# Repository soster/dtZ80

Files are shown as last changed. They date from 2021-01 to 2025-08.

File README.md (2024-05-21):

# dtZ80 - A simple 8 Bit Computer based on the Z80 CPU

This started as a project during the second Corona lockdown, where I had to much free time.
I wanted to design my own 8 Bit computer and decided to use the Z80 CPU.
The first idea was to use a MOS 6502 because a variant of that powers the C64, a computer I used much in my childhood.
The Z80 is easier to source where I live so I used that instead.

I started on breadboards but quickly discovered the limits of that so I soldered some prototypes and finally designed some PCBs with kicad.

The bus is compatible to the Bus of the [RC2014 Z80 computer](https://rc2014.co.uk/), so I can exchange expansion cards.

This documentation now covers the new "Black Edition" of the dtZ80 (Rev 1), a larger board without the need to use extension cards. Previous prototypes had a common bus board and extension cards for the CPU, RAM etc. All software for the previous prototypes can be found at `asm/prototype` for historical reasons.

The dtZ80 uses a Z80 CPU with clocked with 7.3728 Mhz (which doubles as a clock for serial communication), a Z80 SIO for serial communication, a CTC counter timer, 32kb of RAM and 32kb of ROM and a AY-3-8910A sound chip. It uses a single seven segment display for debugging purposes and a 4 line, 20 characters per line LCD for text output.

## Tools

* [rasm](https://github.com/mkoloberdin/rasm) is used as the assembler.
* [Visual Studio Code](https://code.visualstudio.com/) is used as an editor and enviroment for assembler
* [Minipro](https://gitlab.com/DavidGriffith/minipro/) is used to flash the EEPROMs, the hardware is a TL866 II PLUS
* [ticks](https://github.com/z88dk/z88dk) from the z88dk project is used as an emulator / simulator
* A usb to ttl converter for serial communication (can be switched to 5V levels, only needs TX and RX)

## Images

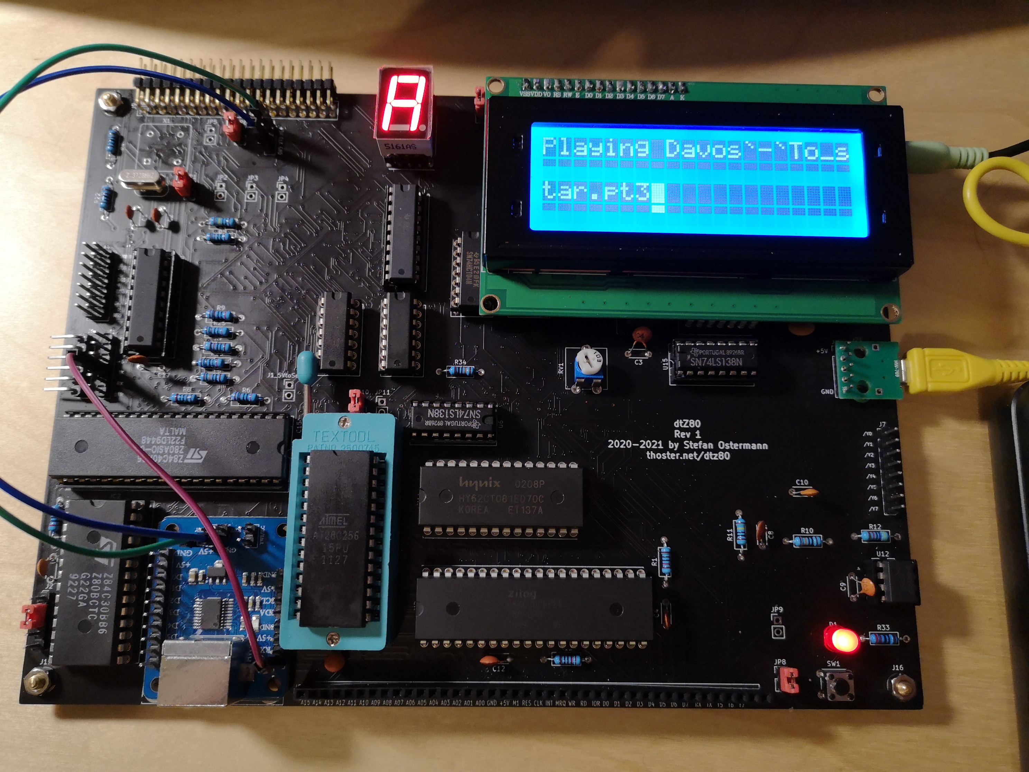
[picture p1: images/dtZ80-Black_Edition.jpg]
dtZ80 Black Edition


### Address Space

Address lines are assigned by a 74LS138 IC (U6) which activates
or deactivates the correct ICs.

    $00: I/O port 7 segment (A0-A7=0)
    $04: LCD command I/O port (A5=1)
    $05: LCD data I/O port (A5=1,A0=1)
    $40: SIO Data Channel A
    $42: SIO Control Channel A
    $60: CTC Channel 0
    $61: CTC Channel 1
    $62: CTC Channel 2
    $63: CTC Channel 3
    $80: Sound Register
    $81: Sound Data

#### LCD

The black edition uses a 4 line, 20 column LCD Display (2004A V1.1) probably based on the HD44780 Chip [(Datasheet)](https://www.sparkfun.com/datasheets/LCD/HD44780.pdf).
It behaves strangely if we send character by character to it, it uses line 3 after line 1 and the lines 2 and 4 are not usable. We have to manually set the DDRAM address holding the character position according to the current line:

    Line 1: $00 - $13
    Line 2: $40 - $53
    Line 3: $14 - $27
    Line 4: $54 - $67

I assume this is due to backwarts compatibility to 2 line displays.

#### Parallel Interface

The 8 Bit parallel Interface is used to connect a lcd screen mainly. Due to an error while designing the pcb, it has the following pins (GND=Pin 1):

Parallel Port

#### Serial Interface

The serial interface is provided by the Z80 SIO chip (SI0/0). It has two channels, A (J1) and B (J6). The clock is provided by the CTC chip for channel A. If you want to use channel B, you have to connect the clock from the pin CTS from J1 to CTS on J6. Please note that RX and TX are labeled from the point of view of the external device, RX is connected to TX on the SIO and vice versa (this maybe was a stupid decistion).

If you are working with linux and you have a usb to serial converter connected to /dev/ttyUSB0 you can use `screen` to enter serial terminal mode:

    screen /dev/ttyUSB0 19200

To enter serial mode of the dtZ80 simply press enter now.

Screen commands consist of "C-a" or ctrl+a (holding down the control key, and then pressing the 'a' key, then releasing both), to enter the command input mode, then commands may be entered with another key stroke.
To disconnect from the session: Ctrl+a, Ctrl+d, you can then use this to reattach to the session:

    screen -r

To quit screen and close connection: ctrl+a, k.

### CTC Clock Timer Chip

TODO

### PS/2 Keyboard module

For ps/2 keyboard to serial conversion I use a "PS2 Keyboard Driver Serial Port Transmission Module".
 
1. connect TX from the module to TX from J1. The module communicates via serial in 19.200 Baud, 1 Stop bit, no parity.

### Sound

TODO

### Simulator / Emulator

The simulator `ticks` from [https://github.com/z88dk/z88dk](https://github.com/z88dk/z88dk) can be used as a simulator. It provides character output for debugging purposes. Use it like this on assembled binary files:

```
z88dk.z88dk-ticks -iochar 5 bios.bin
```
`-iochar 5` puts out characters just like for the LCD of the dtz80.

## Next steps / TODOs

* Further develop the bios
* Tiny Basic example code: http://cpuville.com/Code/tinybasic2dms_asm.txt
* Document all features

### Graphics

Graphics is not finished yet. These are some ideas:
Based on: TMS9918A
Problem: Works only with DRAM for SRAM
Looks like you will need to latch the address bits 8-15 when RAS goes low
Connect (/CAS0 AND /CAS1) to /OE on the SRAM and use one of them for A16 also
Important: Clock 10.738635 Mhz, Type ‎MP107-E‎ for video timing
Use schematics from: https://github.com/jblang/TMS9918A

## Links
* [Bread 80](https://bread80.com/) A Z80 on breadboards
* [RC2014](https://rc2014.co.uk/) Another Z80 project
* [LM80C Color Computer](https://hackaday.io/project/165246-lm80c-color-computer) Another Z80 Computer, interesting because of graphics output
* [Z80 Assembler for dummies](https://www.msx.org/wiki/Z80_Assembler_for_Dummies) Z80 Assembler Guide

## More images
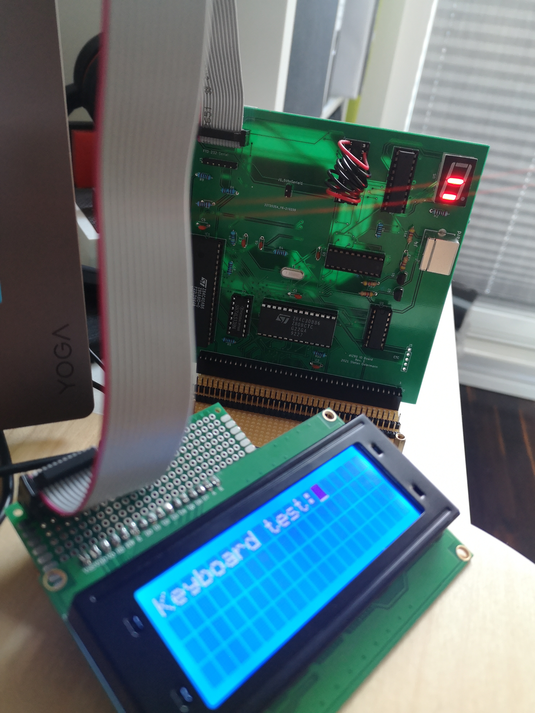
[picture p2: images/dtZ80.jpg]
dtZ80

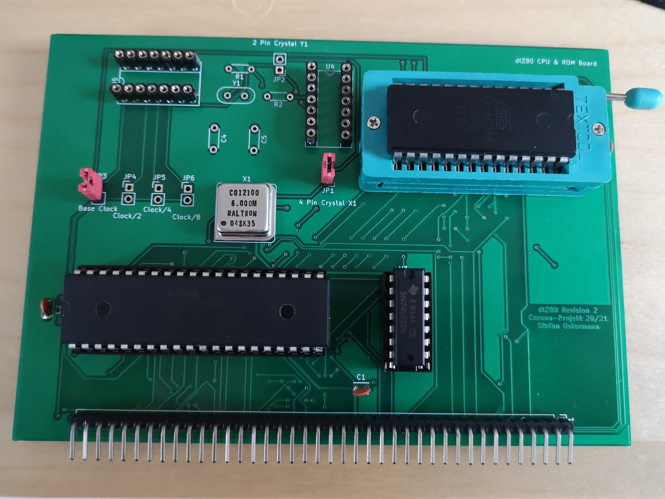
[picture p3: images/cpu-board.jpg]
CPU Card


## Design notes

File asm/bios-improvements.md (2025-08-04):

# dtZ80 BIOS Improvement Recommendations

## Critical Fixes Required

### 1. Fix Syntax Error
**File:** `asm/dtz80-lib.inc`
**Issue:** Standalone 'd' character in STARTUP_SOUND routine
**Fix:** Remove the erroneous 'd' character

### 2. Fix Memory Map
**Current Issue:** RAM starts at $8000 but ROM should end at $7FFF
**Recommended Memory Map:**
```
$0000-$7FFF: ROM (32KB)
$8000-$FFFF: RAM (32KB)
$8000-$8FFF: System variables and buffers
$9000-$EFFF: User RAM
$F000-$FFEF: Stack space
$FFF0-$FFFF: Reserved for I/O
```

### 3. Proper Interrupt Vector Setup
```assembly
; Set interrupt vector base
ld a, $00
ld i, a
im 2

; Calculate proper interrupt vectors
; SIO Channel A RX: Vector base + $0C
; SIO Special RX:   Vector base + $0E
```

## Major Improvements

### 4. Enhanced LCD Library
Replace fixed delays with busy flag checking:
```assembly
LCD_WAIT_BUSY:
    push af
    in a, (LCD_COMMAND)    ; Read busy flag
    bit 7, a               ; Check busy bit
    jr nz, LCD_WAIT_BUSY   ; Wait if busy
    pop af
    ret
```

### 5. Robust Error Handling
```assembly
SPEC_RX_CONDITON:
    push af
    push hl
    
    ; Check error type
    ld a, 1
    out (SIO_CA), a        ; Select RR1
    in a, (SIO_CA)         ; Read error status
    
    bit 6, a               ; Overrun error?
    jr nz, HANDLE_OVERRUN
    bit 5, a               ; Framing error?
    jr nz, HANDLE_FRAMING
    bit 4, a               ; Parity error?
    jr nz, HANDLE_PARITY
    
    ; Clear error and continue
    call RX_EMP
    pop hl
    pop af
    ei
    reti

HANDLE_OVERRUN:
    ; Log error and reset
    call RX_EMP
    ; Could increment error counter here
    jr ERROR_EXIT
```

### 6. Improved Constants Definition
```assembly
; Memory Map Constants
ROM_START       equ $0000
ROM_END         equ $7FFF
RAM_START       equ $8000
RAM_END         equ $FFFF
STACK_TOP       equ $FFEF

; I/O Port Constants  
LCD_BASE        equ $04
SEVENSEG_BASE   equ $00
SIO_BASE        equ $40
CTC_BASE        equ $60
SOUND_BASE      equ $80

; System Constants
BAUD_RATE       equ 19200
CPU_FREQ        equ 7372800
```

### 7. Enhanced Startup Sequence
```assembly
MAIN:
    di                      ; Disable interrupts during init
    ld sp, STACK_TOP        ; Set stack pointer
    
    ; Hardware initialization
    call INIT_MEMORY        ; Clear and test RAM
    call INIT_CTC           ; Setup CTC
    call INIT_SIO           ; Setup SIO
    call INIT_SOUND         ; Setup AY-3-8910A
    call INIT_LCD           ; Setup LCD
    
    ; System initialization
    call INIT_VARIABLES     ; Initialize system variables
    call INIT_INTERRUPTS    ; Setup interrupt vectors
    
    ; Display startup message
    call DISPLAY_BANNER
    call POST_TEST          ; Power-on self test
    
    ei                      ; Enable interrupts
    jp MAIN_LOOP
```

### 8. Better Command Processing
```assembly
; Command table structure
CMD_TABLE:
    dw CMD_CLEAR, OC_CLEAR
    dw CMD_VERSION, OC_VERSION  
    dw CMD_RESET, OC_RESET
    dw CMD_PLAY, OC_PLAY
    dw 0                    ; End marker

CHECK_OPCODE:
    ld hl, CMD_TABLE
CHECK_LOOP:
    ld e, (hl)              ; Get command handler address
    inc hl
    ld d, (hl)
    inc hl
    ld a, d
    or e                    ; Check for end marker
    ret z                   ; No more commands
    
    push de                 ; Save handler address
    ld e, (hl)              ; Get command string address
    inc hl
    ld d, (hl)
    inc hl
    
    push hl                 ; Save table position
    ld hl, LAST_OPCODE
    ld bc, OPCODE_LENGTH
    call STRCMP
    pop hl                  ; Restore table position
    pop de                  ; Restore handler address
    
    jr z, EXECUTE_COMMAND   ; Found match
    jr CHECK_LOOP           ; Try next command

EXECUTE_COMMAND:
    ex de, hl               ; Handler address to HL
    jp (hl)                 ; Execute command
```

## Minor Improvements

### 9. Code Organization
- Separate hardware-specific code into modules
- Create proper header files with constants
- Add comprehensive comments
- Use consistent naming conventions

### 10. Additional Features to Consider
- Watchdog timer support
- Better debugging facilities
- Configuration storage in EEPROM
- More robust PS/2 keyboard handling
- Sound effects library
- Simple file system for storing programs

### 11. Testing Improvements
- Add comprehensive POST tests
- Memory test routines
- I/O port test routines
- Interrupt test routines

## Implementation Priority

1. **High Priority:** Fix syntax error and memory map
2. **High Priority:** Implement proper interrupt handling
3. **Medium Priority:** Improve LCD library with busy flag checking
4. **Medium Priority:** Enhanced error handling
5. **Low Priority:** Code organization and additional features

These improvements will make your dtZ80 BIOS more robust, maintainable, and feature-rich while maintaining compatibility with the RC2014 bus standard.

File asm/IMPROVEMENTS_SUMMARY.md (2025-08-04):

# dtZ80 BIOS Improvements Implementation Summary

## Completed Fixes and Improvements

### 1. ✅ **CRITICAL: Fixed Syntax Error**
- **File:** `asm/dtz80-lib.inc`
- **Issue:** Removed erroneous standalone 'd' character in STARTUP_SOUND routine
- **Status:** FIXED - This was preventing assembly

### 2. ✅ **HIGH PRIORITY: Fixed Memory Map**
- **Files:** `asm/dtz80-lib.inc`, `asm/bios.asm`, `asm/debug-bios.inc`
- **Changes:**
  - Added proper memory map constants (ROM_START, ROM_END, RAM_START, RAM_END)
  - Set STACK_TOP to $FFEF (leaving space for I/O at top of memory)
  - Updated STACKPOINTER to use STACK_TOP
  - Fixed all references to use STACKPOINTER consistently
- **Status:** IMPLEMENTED

### 3. ✅ **HIGH PRIORITY: Improved Interrupt Handling**
- **File:** `asm/bios.asm`
- **Changes:**
  - Enhanced interrupt vector setup with better documentation
  - Improved interrupt mode 2 initialization
  - Added proper comments explaining vector calculation
- **Status:** IMPLEMENTED

### 4. ✅ **MEDIUM PRIORITY: Enhanced Error Handling**
- **File:** `asm/bios.asm`
- **Changes:**
  - Completely rewrote SPEC_RX_CONDITON handler
  - Added proper SIO error type detection (overrun, framing, parity)
  - Implemented specific error handling for each error type
  - Added proper register preservation and error cleanup
  - Added error reset command to clear SIO error flags
- **Status:** IMPLEMENTED

### 5. ✅ **MEDIUM PRIORITY: Improved LCD Library with Busy Flag Checking**
- **File:** `asm/lcd-lib.inc`
- **Changes:**
  - Replaced fixed delays with busy flag checking in LCD_WAIT
  - Added timeout protection to prevent infinite loops
  - Implemented fallback delay mechanism if busy flag fails
  - More reliable LCD communication
- **Status:** IMPLEMENTED

### 6. ✅ **Additional Improvements**
- **File:** `asm/dtz80-lib.inc`
- **Changes:**
  - Added system constants (BAUD_RATE, CPU_FREQ)
  - Better organization of constants
- **Status:** IMPLEMENTED

## Testing Instructions

### Prerequisites
Install rasm assembler:
```bash
# Download and install rasm from: https://github.com/mkoloberdin/rasm
```

### Assembly Test
```bash
cd asm
rasm bios.asm bios
```

### Simulation Test (if z88dk is available)
```bash
# Test with simulator
z88dk-ticks -iochar 5 bios.bin

# Test with symbols for debugging
rasm -s -sa bios.asm bios
z88dk-ticks -x bios.sym -pc 0 -d -iochar 5 bios.bin
```

## Key Benefits of These Improvements

### Reliability
- **Busy flag checking** makes LCD operations more reliable across different LCD modules
- **Enhanced error handling** prevents system crashes from serial communication errors
- **Proper memory map** prevents conflicts between ROM and RAM

### Maintainability
- **Better constants organization** makes code easier to understand and modify
- **Improved documentation** explains complex interrupt handling
- **Consistent naming** throughout the codebase

### Robustness
- **Timeout protection** prevents infinite loops in LCD operations
- **Proper error recovery** handles serial communication problems gracefully
- **Stack placement** leaves room for future I/O expansion

## Remaining Recommendations (Future Work)

### Low Priority Improvements
1. **Command Table System** - Implement table-driven command processing for easier expansion
2. **Memory Test Routines** - Add comprehensive POST tests
3. **Configuration Storage** - Add EEPROM support for storing settings
4. **Enhanced Sound Library** - Better AY-3-8910A support
5. **Watchdog Timer** - Add system reliability features

### Code Organization
1. **Modular Structure** - Separate hardware-specific code into modules
2. **Header Files** - Create proper header files with all constants
3. **Documentation** - Add comprehensive inline documentation

## Compatibility
All improvements maintain full compatibility with:
- RC2014 bus standard
- Existing hardware configuration
- Current I/O port assignments
- Serial communication protocols

## Files Modified
- `asm/bios.asm` - Main BIOS file
- `asm/dtz80-lib.inc` - Main library with constants and routines
- `asm/lcd-lib.inc` - LCD library with busy flag checking
- `asm/debug-bios.inc` - Debug BIOS for simulation
- `asm/bios-improvements.md` - Detailed improvement documentation

The BIOS should now be significantly more robust and reliable while maintaining all existing functionality.

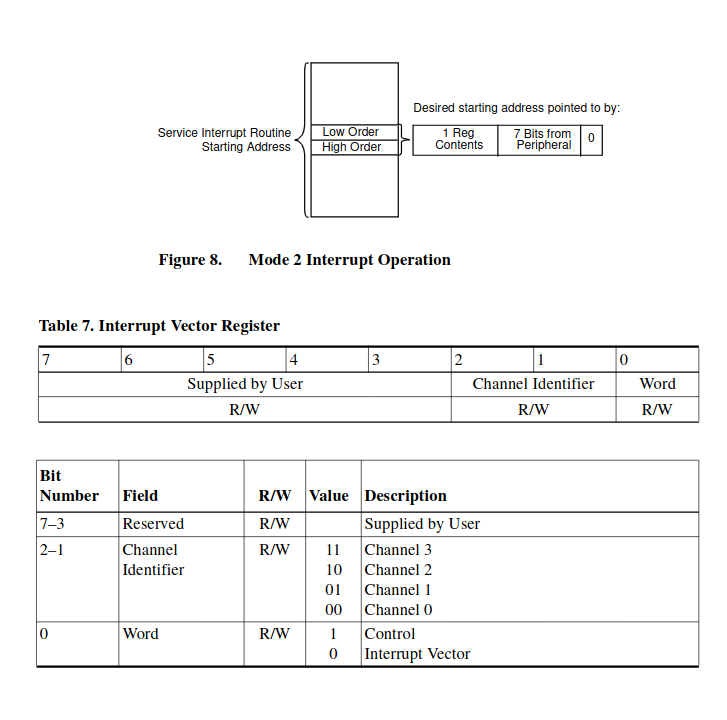
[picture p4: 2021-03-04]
images/ctc-interrupt-vector.png

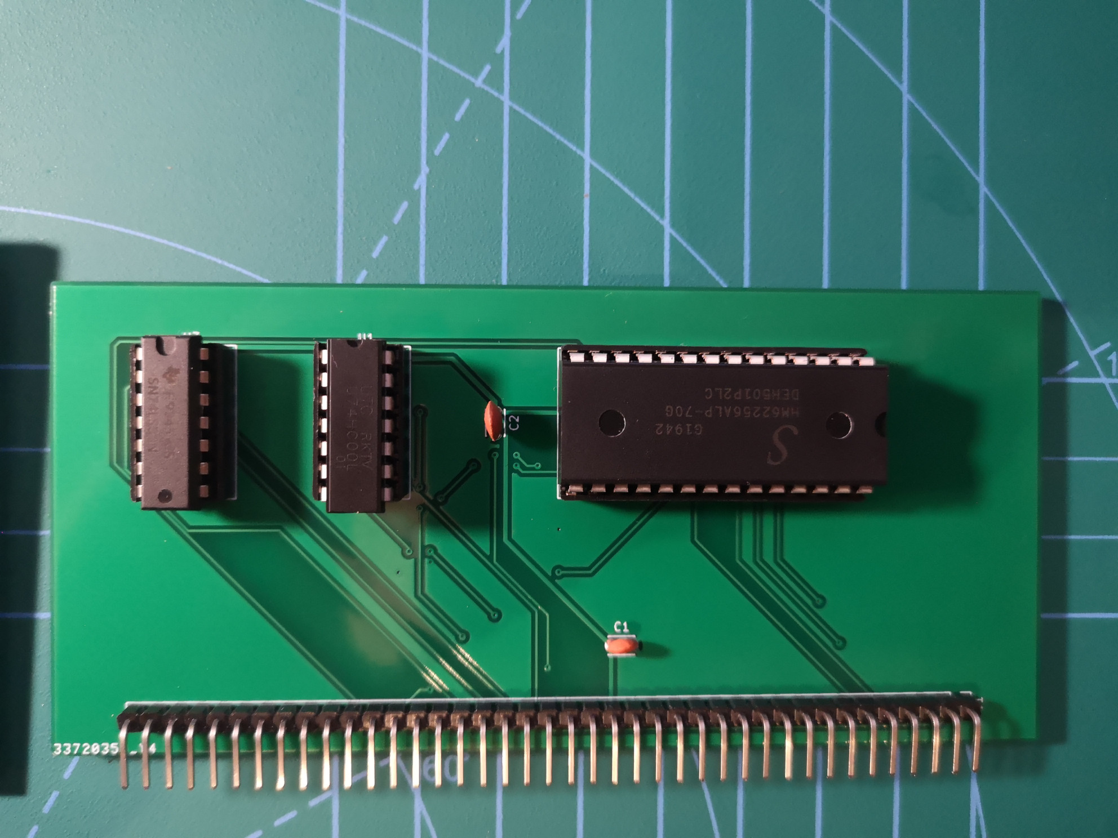
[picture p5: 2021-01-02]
images/memory-board.jpg

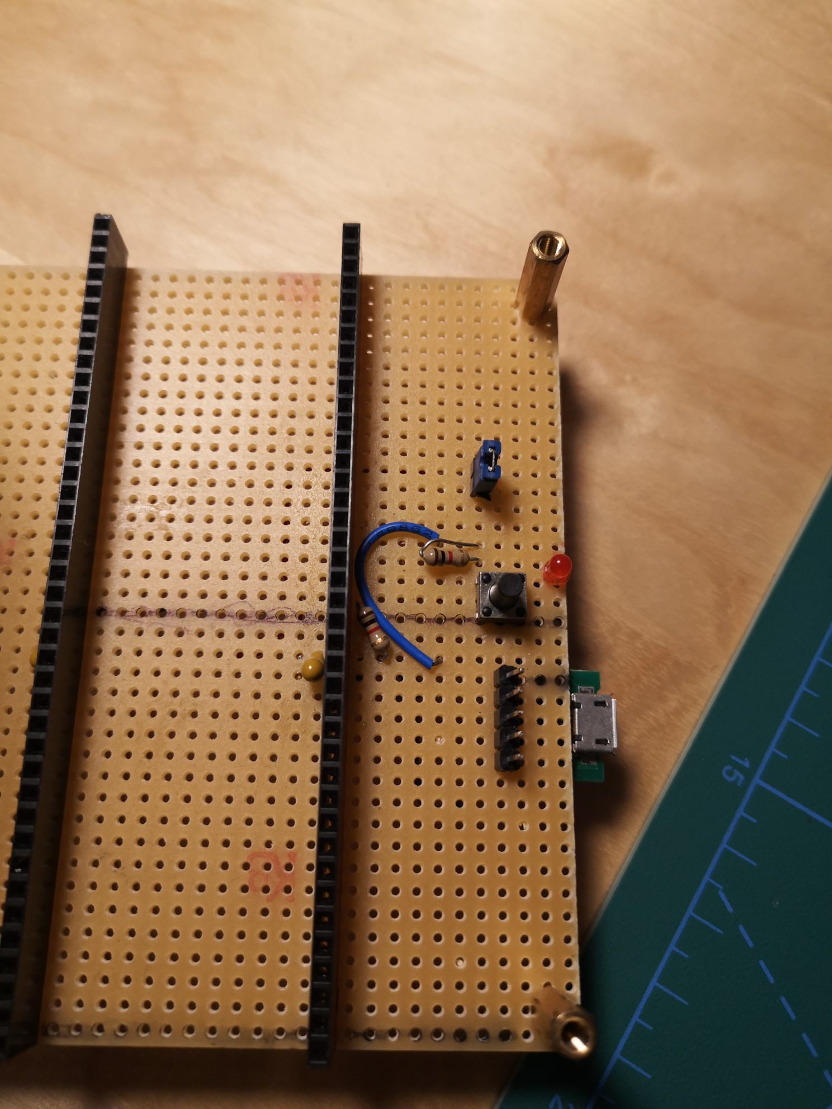
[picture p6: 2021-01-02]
images/mainboard.jpg

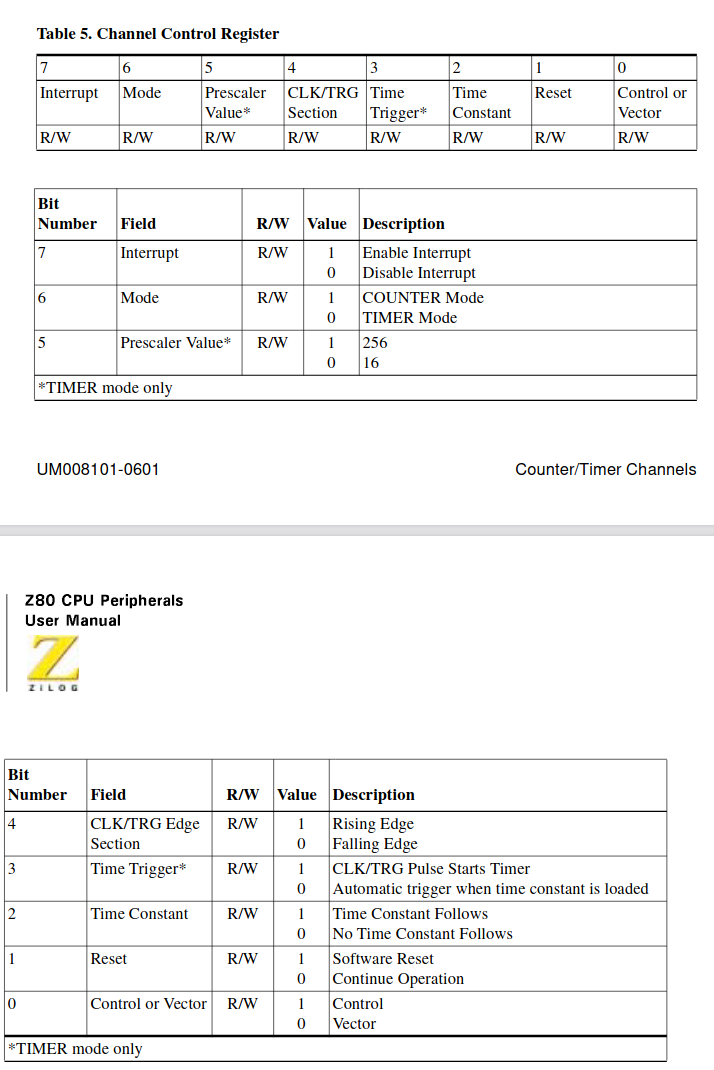
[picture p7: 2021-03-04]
images/ctc-table.png

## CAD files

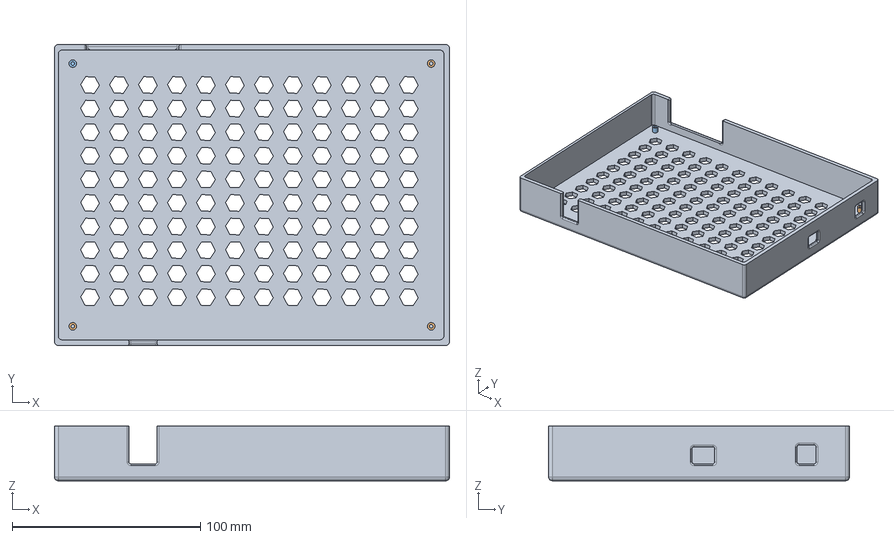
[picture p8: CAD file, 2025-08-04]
case/dtz80-case.step
210.0 x 160.0 x 29.0 mm

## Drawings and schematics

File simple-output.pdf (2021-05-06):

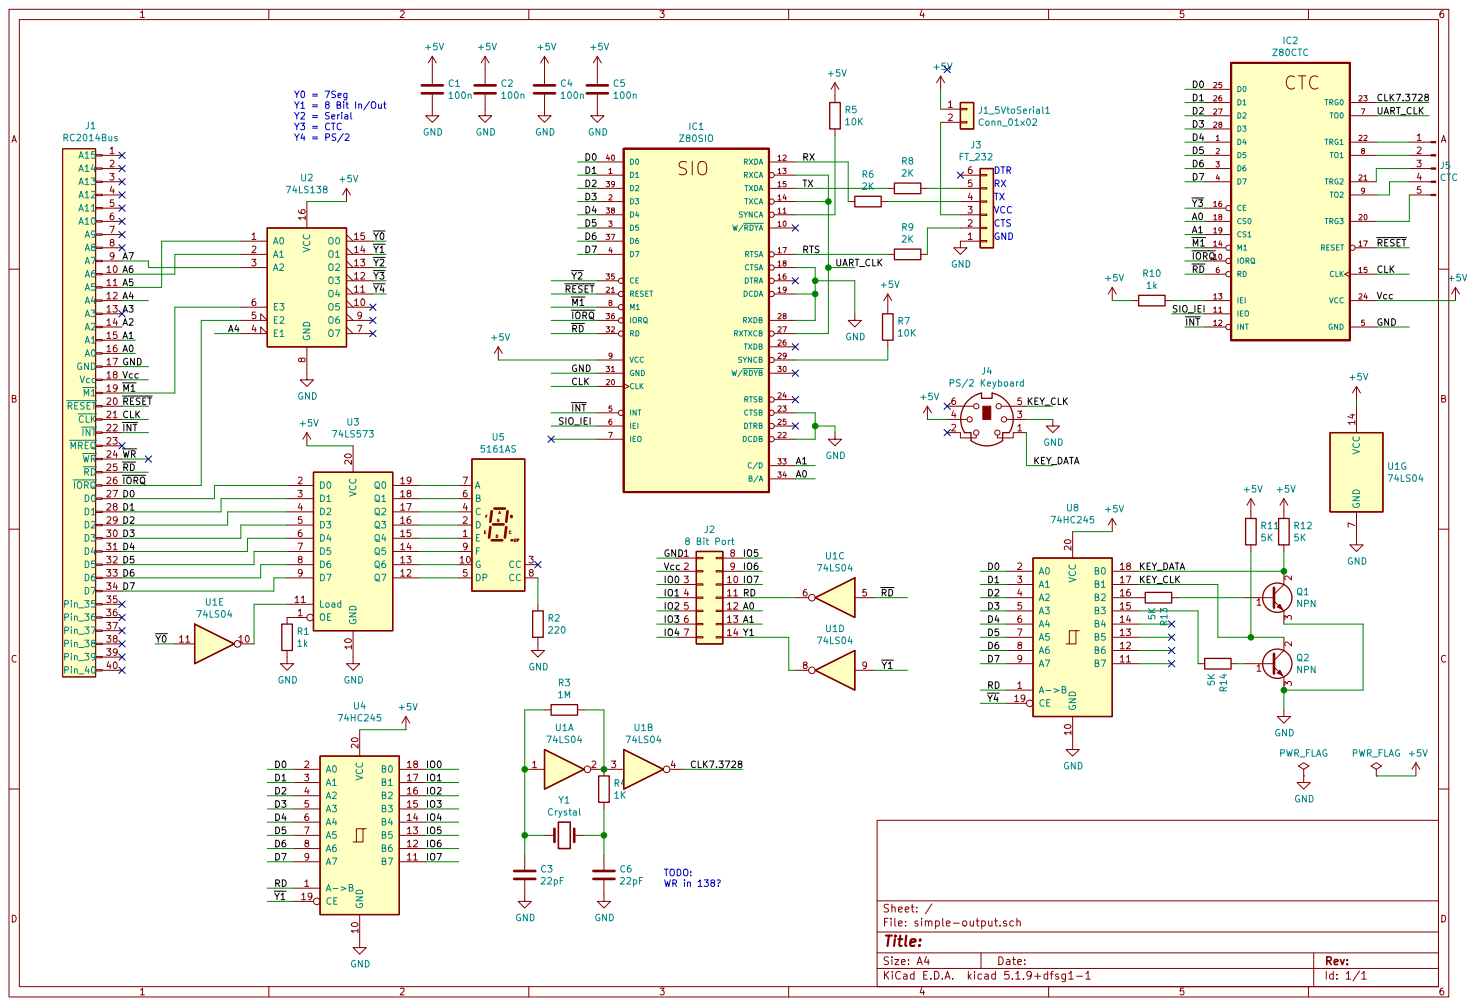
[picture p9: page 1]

Y0 = 7Seg Y1 = 8 Bit In/Out Y2 = Serial Y3 = CTC
100n +5V GND

File: simple-output.sch Sheet: /
Id: 1/1 Title:

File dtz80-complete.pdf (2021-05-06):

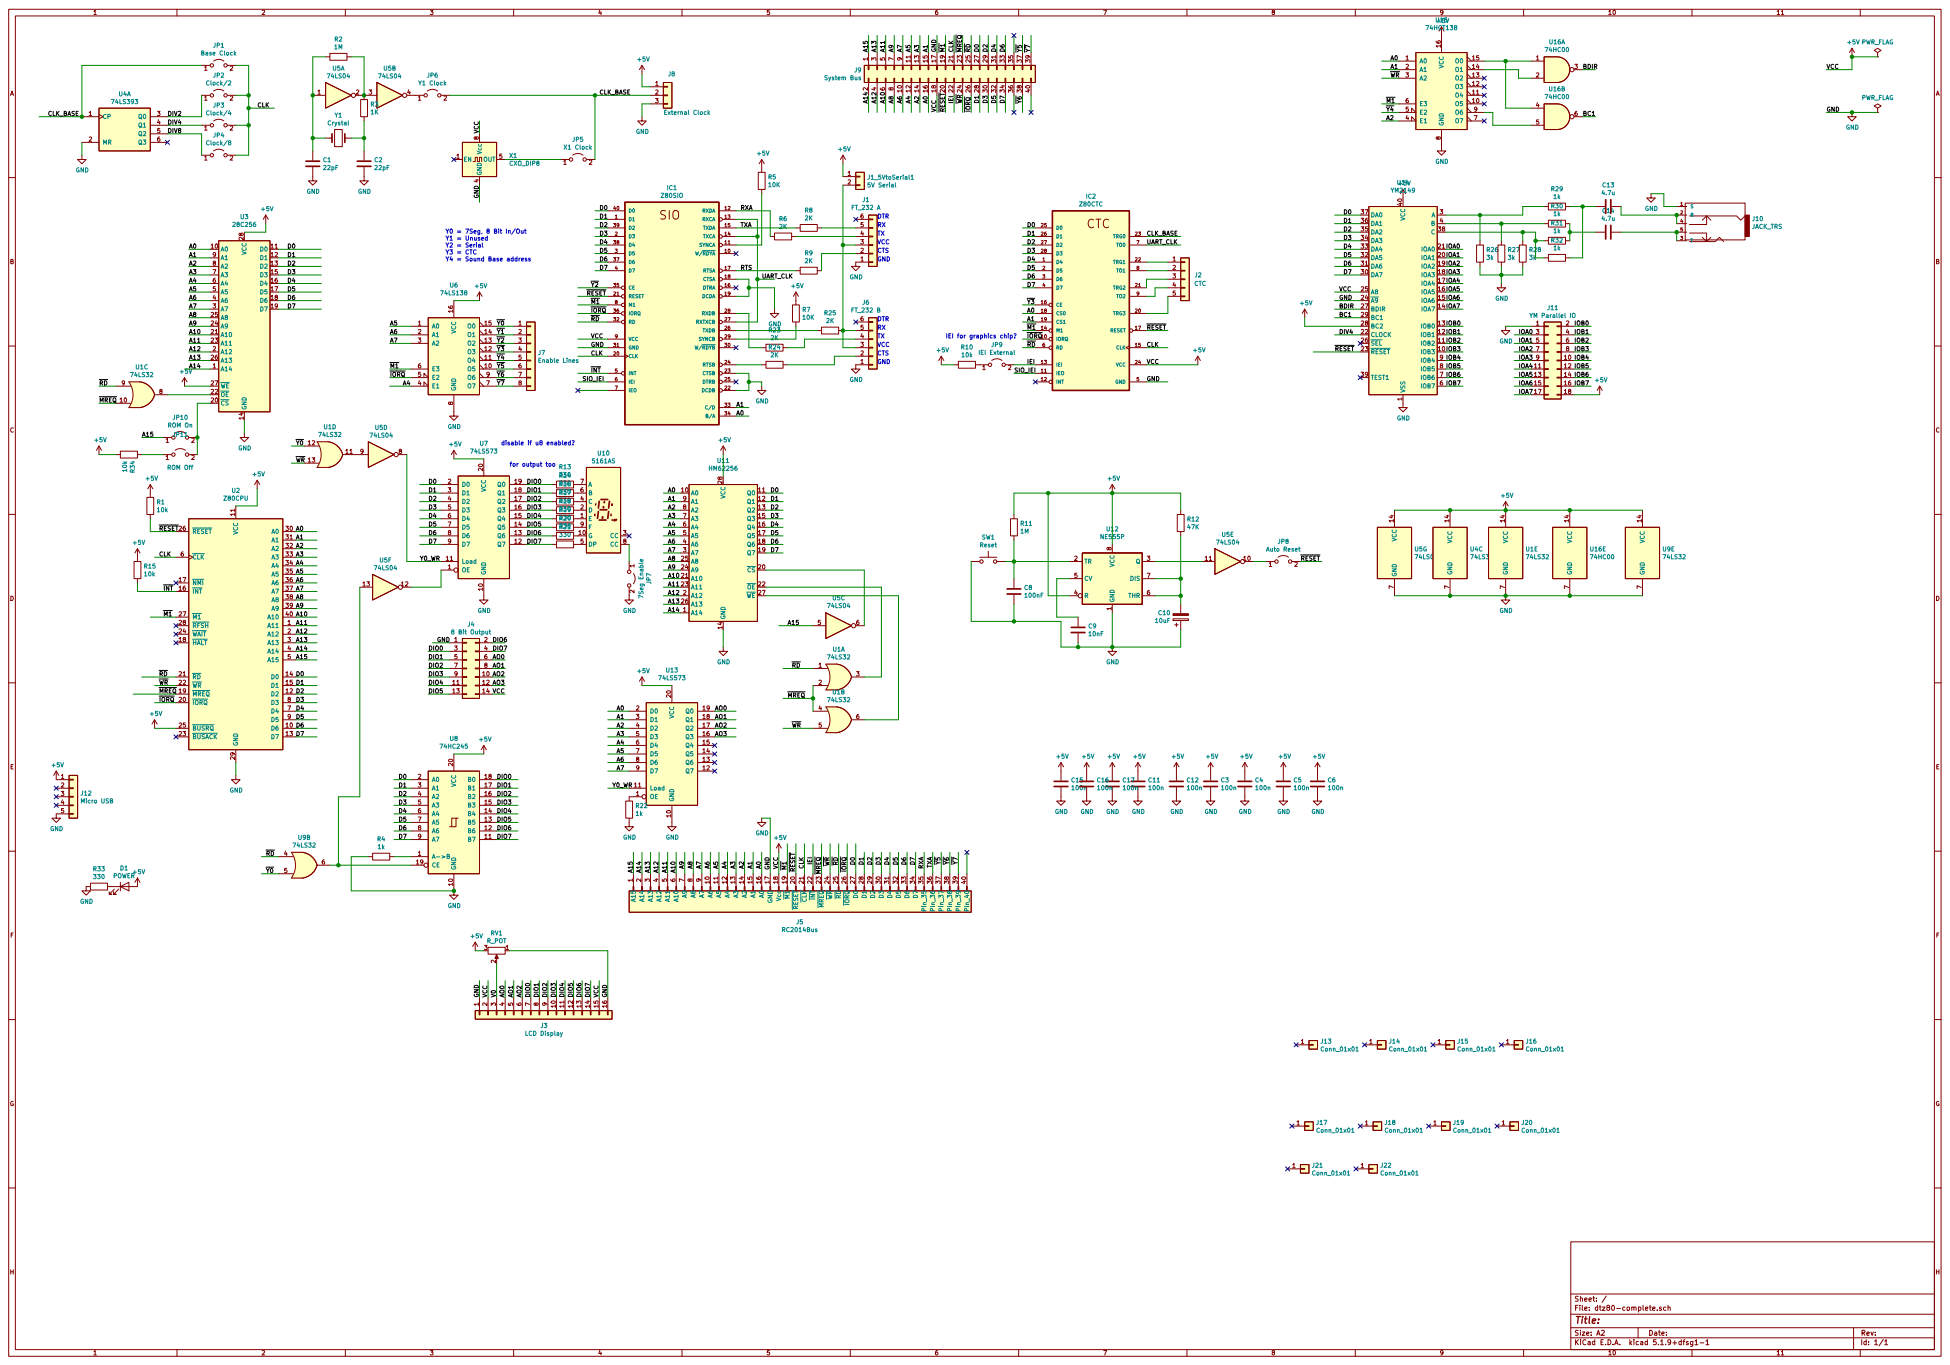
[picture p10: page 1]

disable if u8 enabled? Y0 = 7Seg, 8 Bit In/Out Y1 = Unused Y2 = Serial Y3 = CTC

IEI for graphics chip?

2 RESET 20 CLK 21 INT 22 MREQ 23 WR 24 RD 25 IORQ 26 D0 27 D1 28 D2 29 A13

File: dtz80-complete.sch Sheet: /

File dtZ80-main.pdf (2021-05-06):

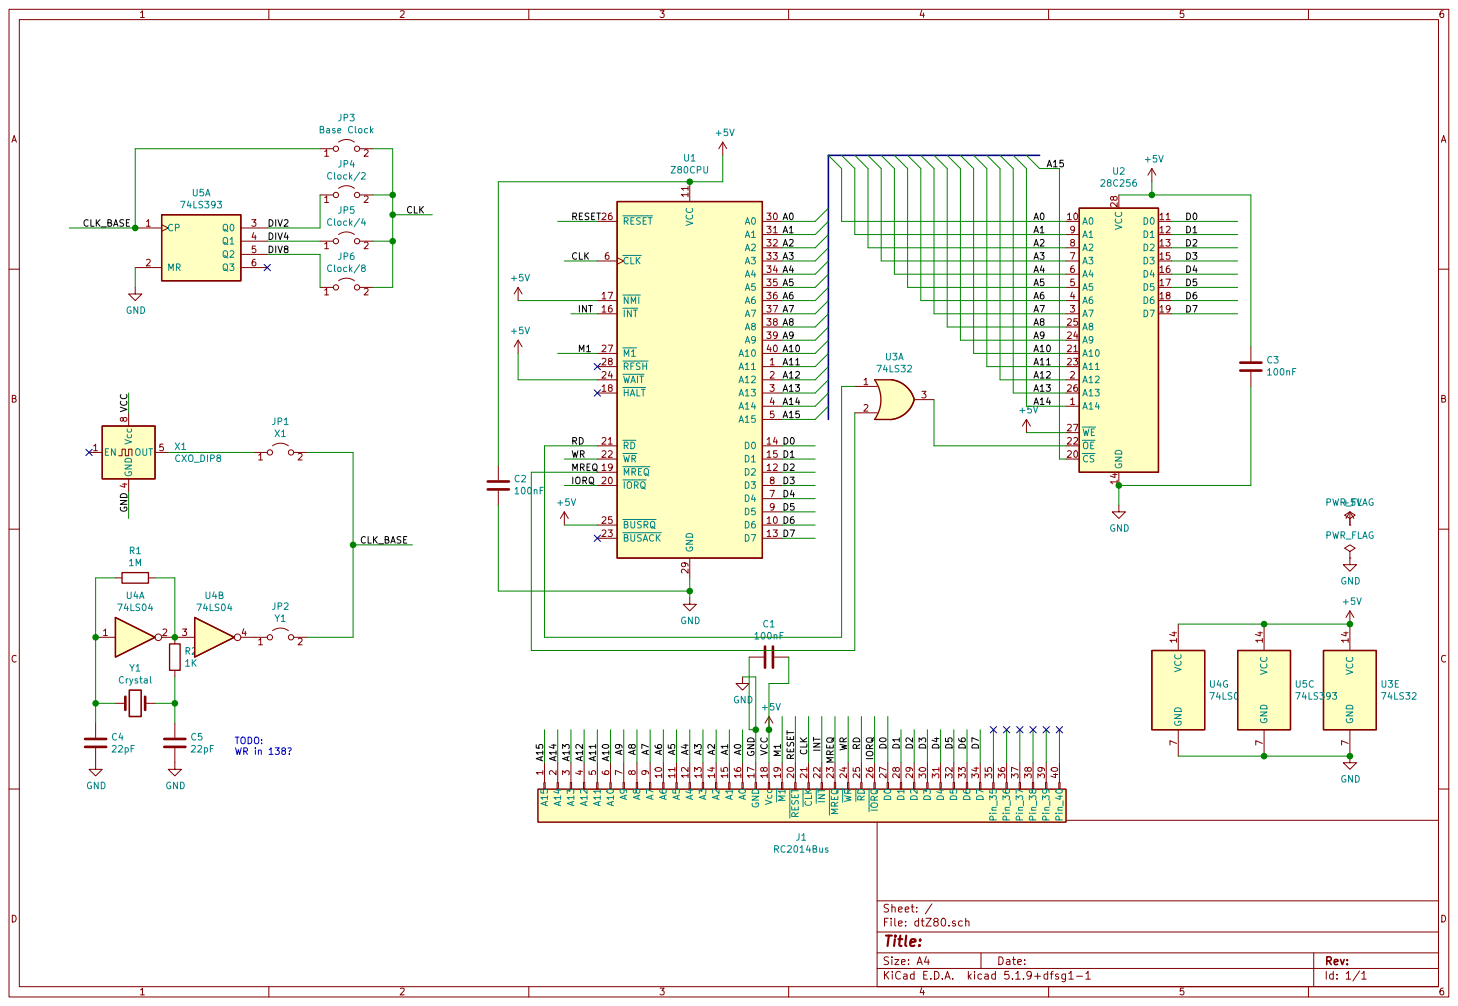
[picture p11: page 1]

Id: 1/1 Title: File: dtZ80.sch Sheet: / C5

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

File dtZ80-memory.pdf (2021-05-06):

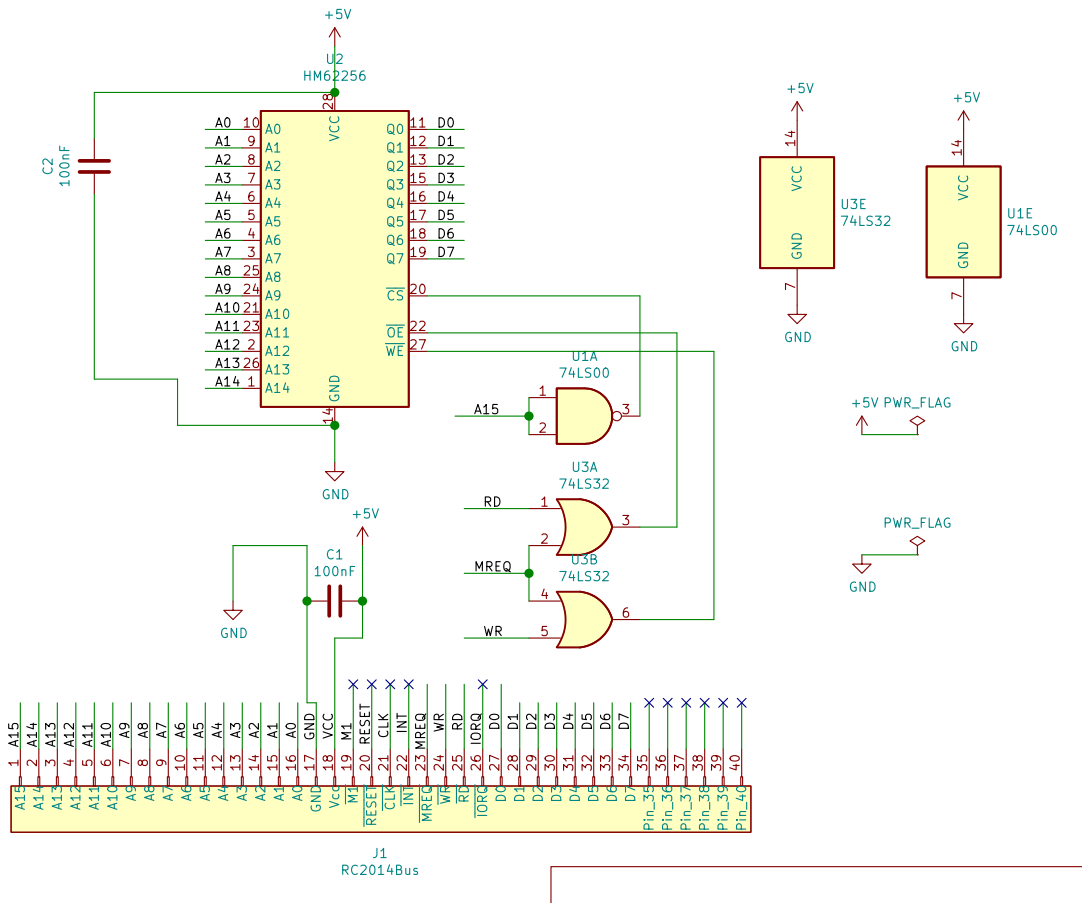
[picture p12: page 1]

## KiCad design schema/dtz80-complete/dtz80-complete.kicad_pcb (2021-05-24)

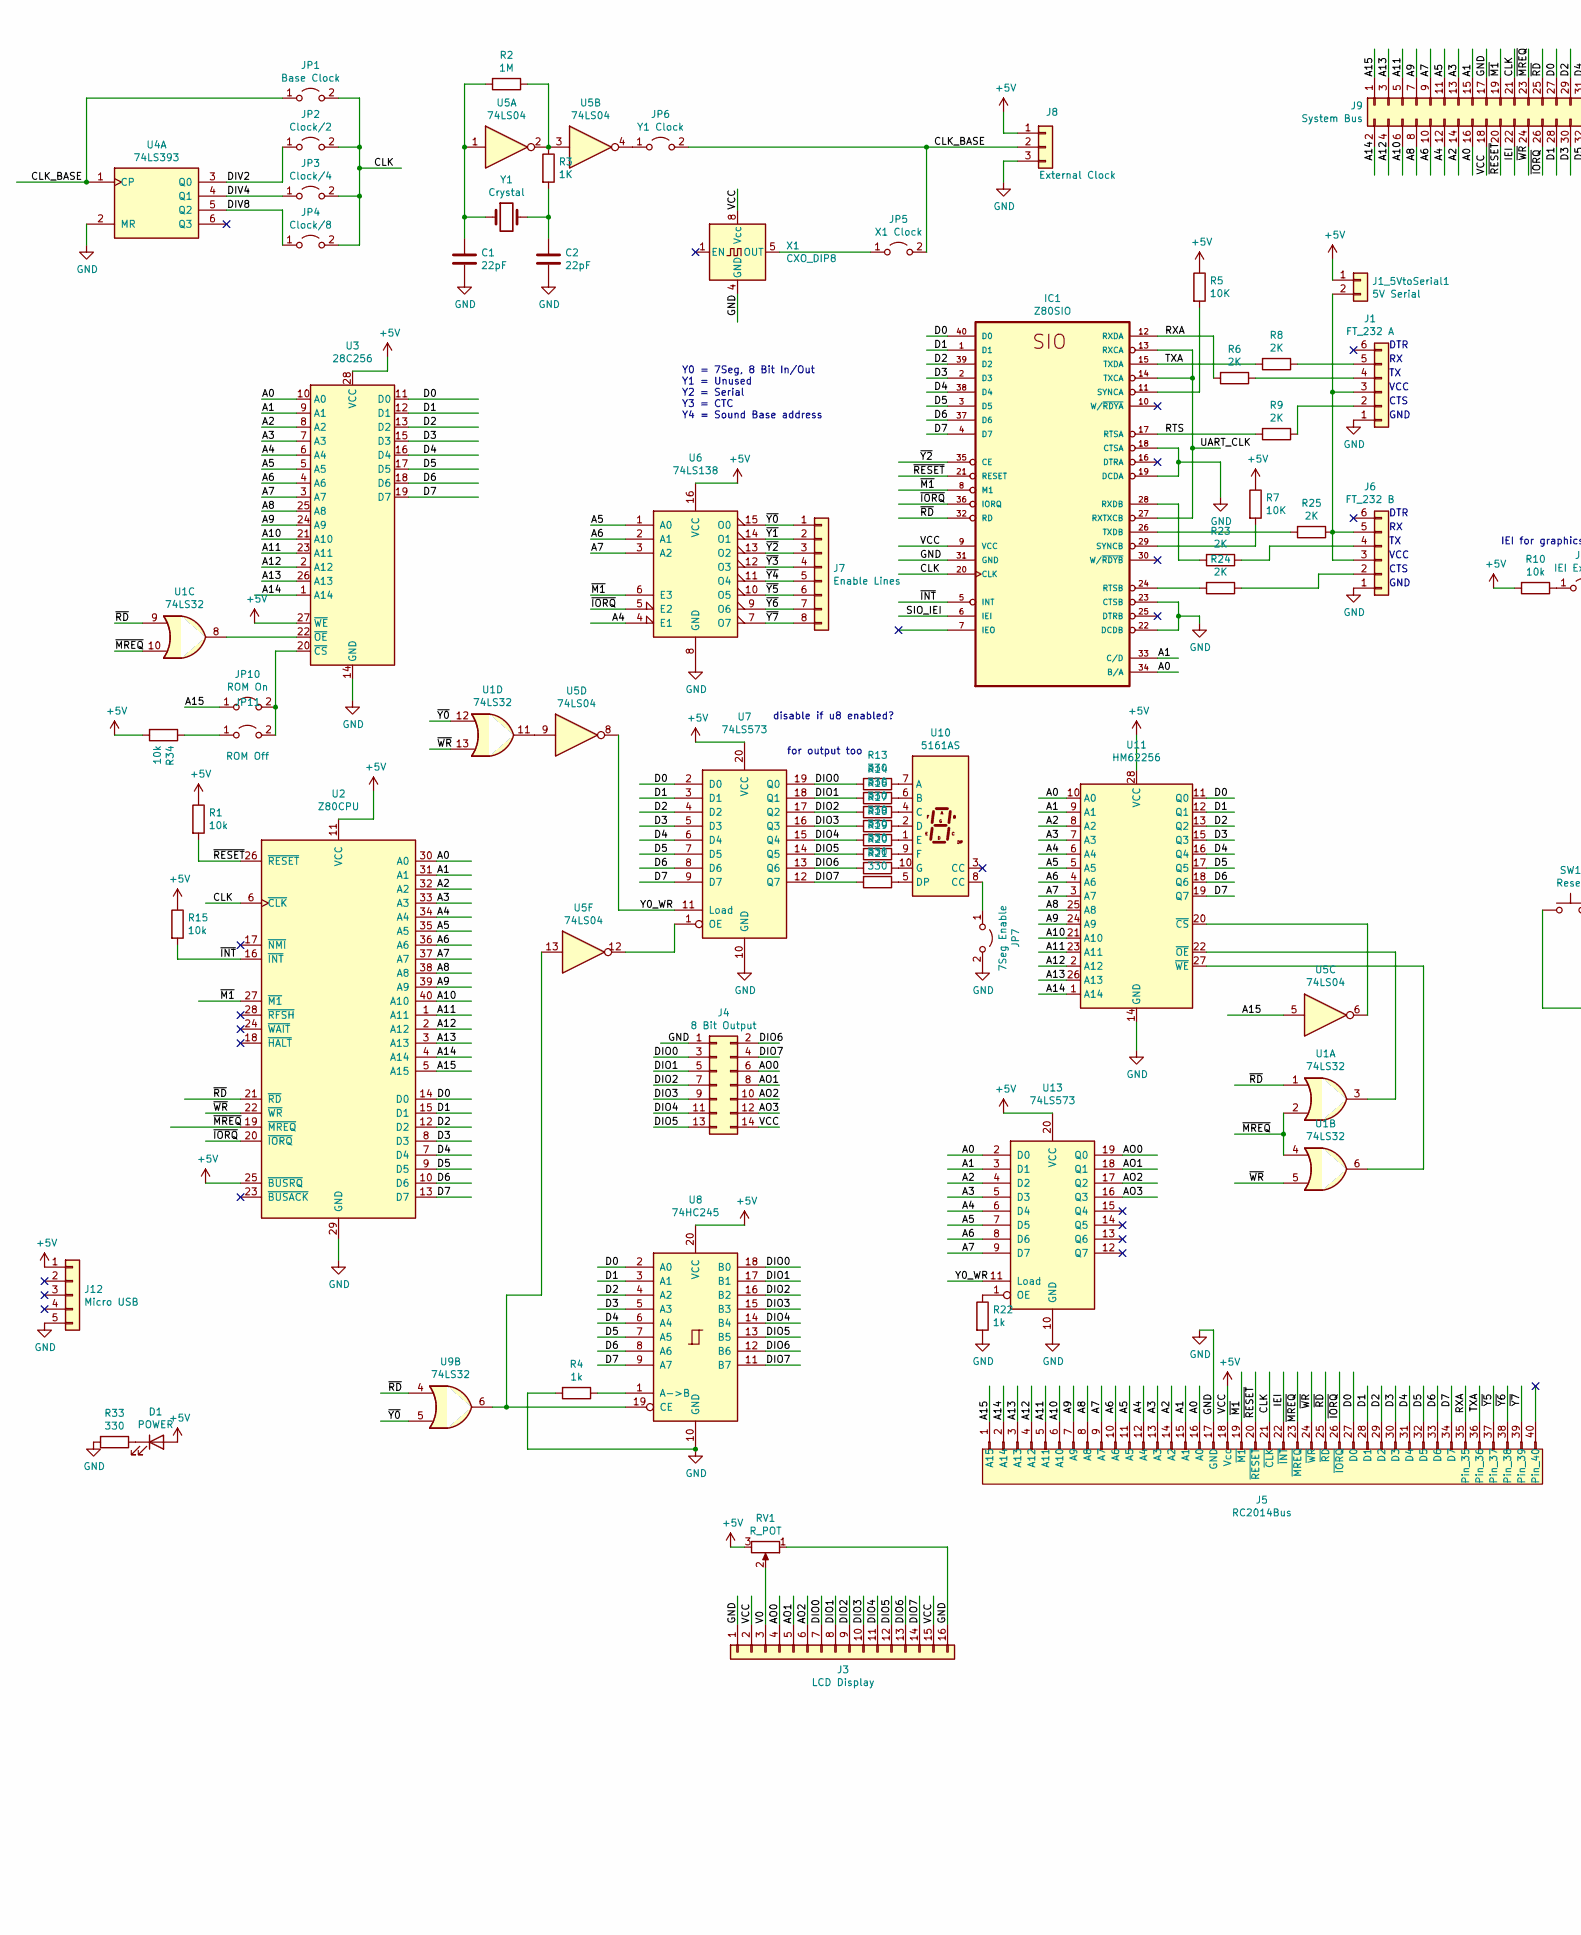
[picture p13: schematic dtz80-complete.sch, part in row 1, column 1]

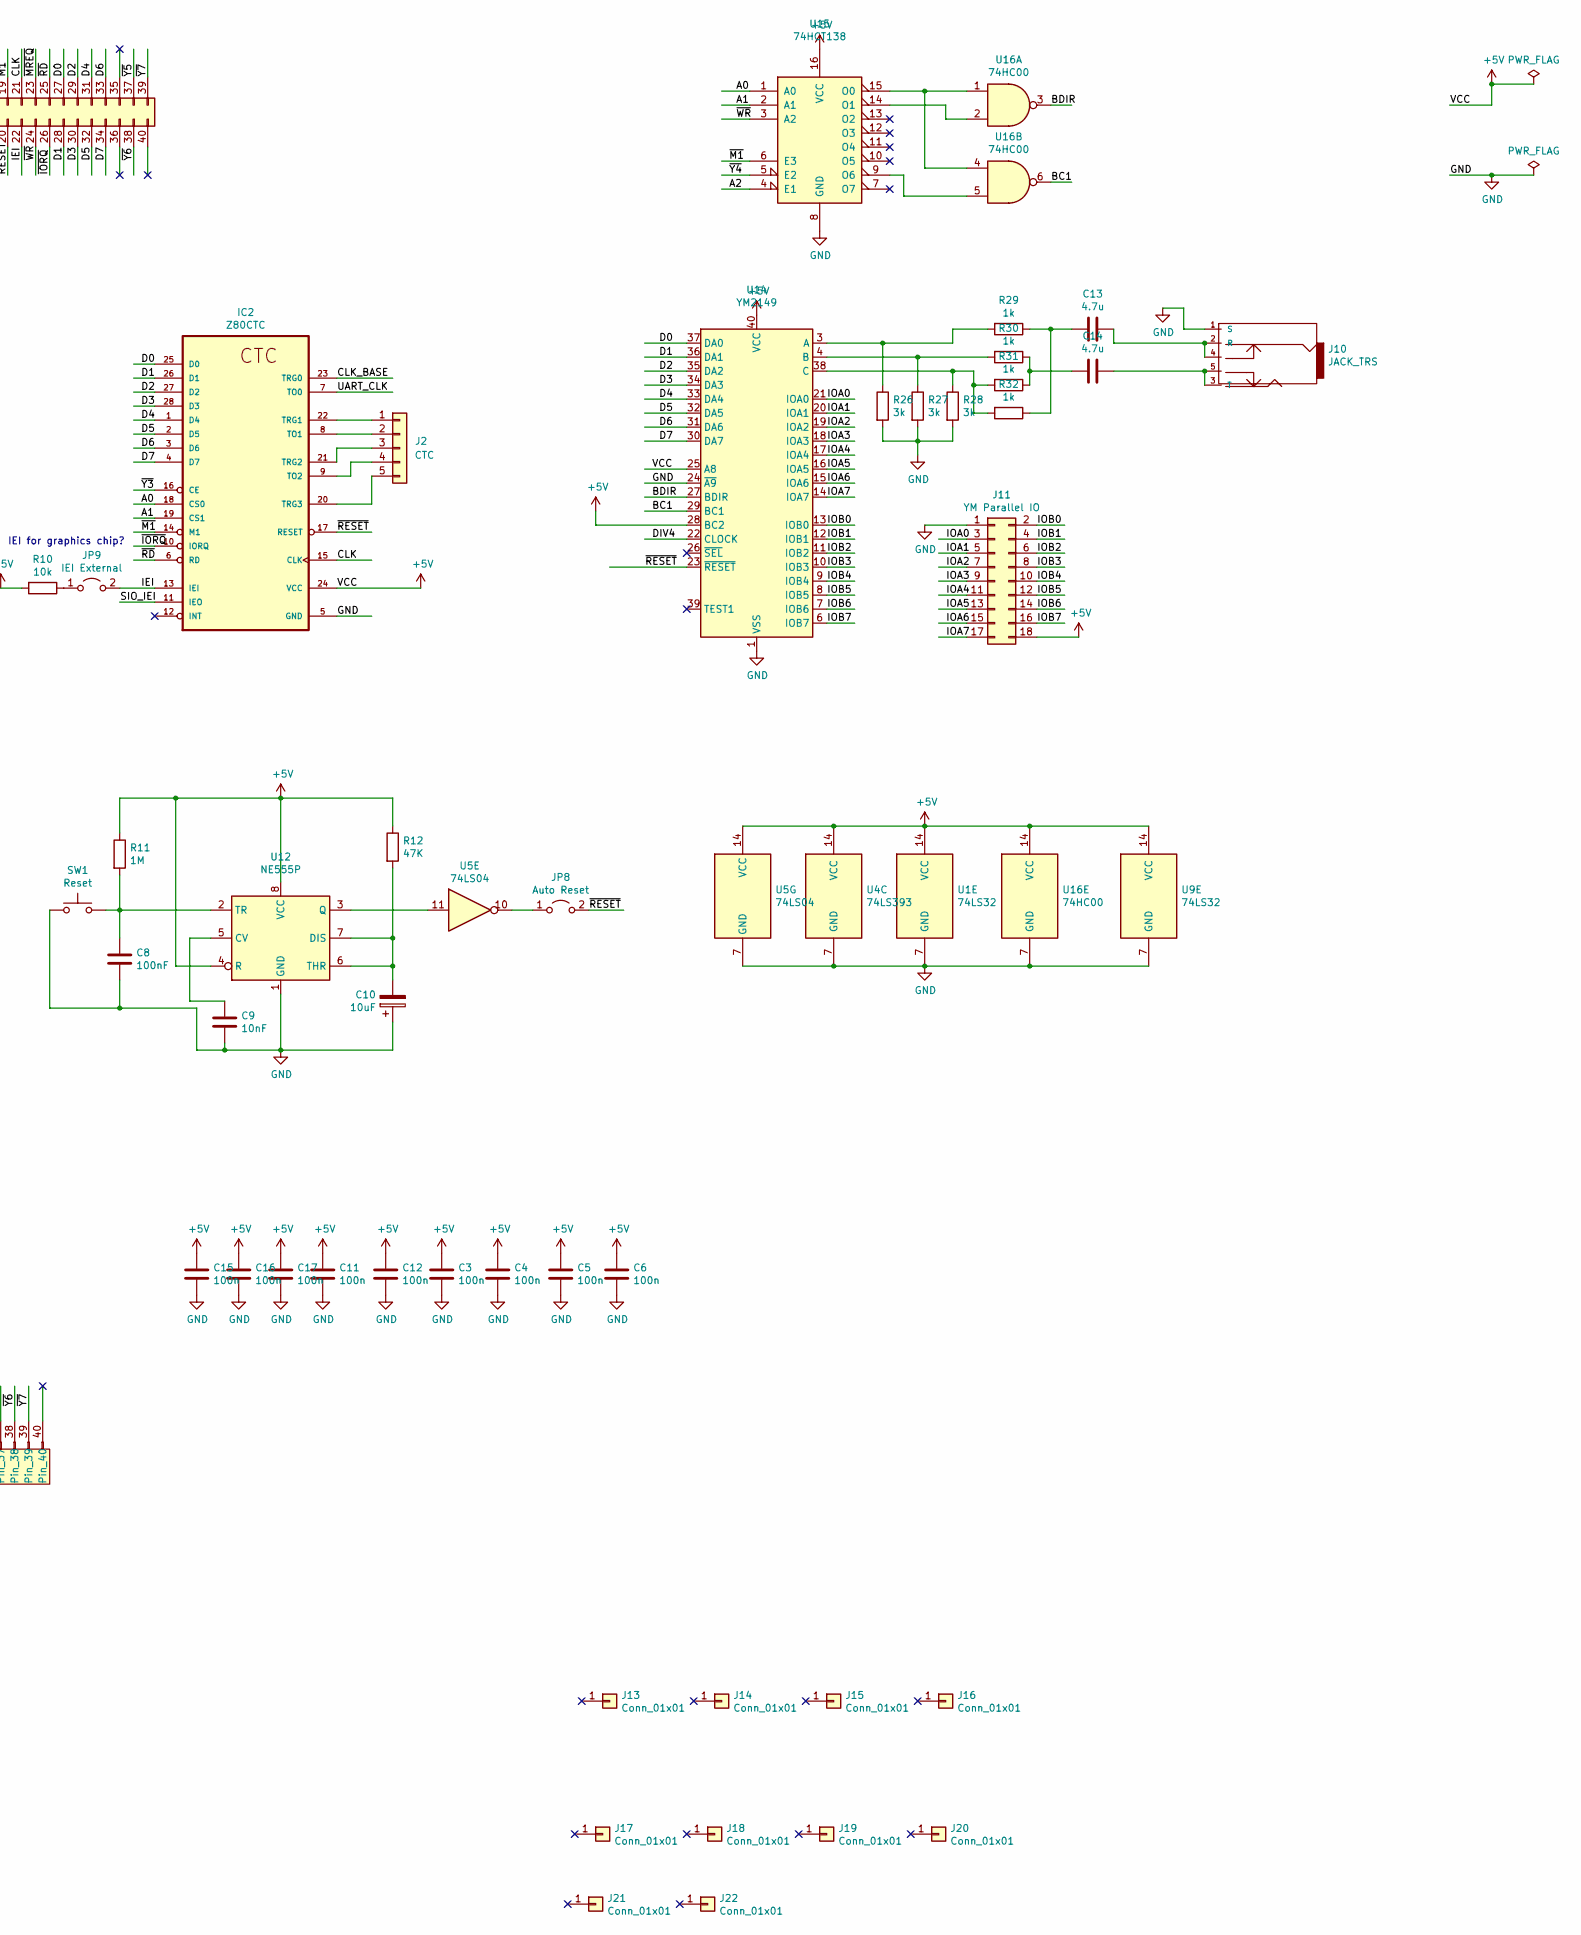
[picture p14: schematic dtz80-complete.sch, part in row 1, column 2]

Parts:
C1, C2: 22pF; C_Disc_D4.3mm_W1.9mm_P5.00mm
C3, C4, C5, C6, C11, C12, C15, C16, C17: 100n; C_Disc_D4.3mm_W1.9mm_P5.00mm
C8: 100nF; C_Disc_D4.3mm_W1.9mm_P5.00mm
C9: 10nF; C_Disc_D4.3mm_W1.9mm_P5.00mm
C10: 10uF; C_Disc_D4.3mm_W1.9mm_P5.00mm
C13, C14: 4.7u; C_Radial_D6.3mm_H5.0mm_P2.50mm
D1: POWER; LED_D3.0mm
IC1: Z80SIO; DIP-40_W15.24mm_Socket
IC2: Z80CTC; DIP-28_W15.24mm_Socket
J1: FT_232 A; PinHeader_1x06_P2.54mm_Vertical
J1_5VtoSerial1: 5V Serial; PinHeader_1x02_P2.54mm_Vertical
J2: CTC; PinHeader_1x05_P2.54mm_Vertical
J3: LCD Display; PinHeader_1x16_P2.54mm_Vertical
J4: 8 Bit Output; PinHeader_2x07_P2.54mm_Vertical
J5: RC2014Bus; PinHeader_1x40_P2.54mm_Vertical
J6: FT_232 B; PinHeader_1x06_P2.54mm_Vertical
J7: Enable Lines; PinHeader_1x08_P2.54mm_Vertical
J8: External Clock; PinHeader_1x03_P2.54mm_Vertical
J9: System Bus; PinHeader_2x20_P2.54mm_Vertical
J10: JACK_TRS; Tayda_3.5mm_stereo_TRS_jack_A-853
J11: YM Parallel IO; PinHeader_2x09_P2.54mm_Vertical
J12: Micro USB; PinHeader_1x05_P2.54mm_Vertical
J13, J14, J15, J16, J17, J18, J19, J20, J21, J22: Conn_01x01; MountingHole_3.2mm_M3_DIN965_Pad
JP1: Base Clock; PinHeader_1x02_P2.54mm_Vertical
JP2: Clock/2; PinHeader_1x02_P2.54mm_Vertical
JP3: Clock/4; PinHeader_1x02_P2.54mm_Vertical
JP4: Clock/8; PinHeader_1x02_P2.54mm_Vertical
JP5: X1 Clock; PinHeader_1x02_P2.54mm_Vertical
JP6: Y1 Clock; PinHeader_1x02_P2.54mm_Vertical
JP7: 7Seg Enable; PinHeader_1x02_P2.54mm_Vertical
JP8: Auto Reset; PinHeader_1x02_P2.54mm_Vertical
JP9: IEI External; PinHeader_1x02_P2.54mm_Vertical
JP10: ROM On; PinHeader_1x02_P2.54mm_Vertical
JP11: ROM Off; PinHeader_1x02_P2.54mm_Vertical
R1, R10, R15, R34: 10k; R_Axial_DIN0207_L6.3mm_D2.5mm_P10.16mm_Horizontal
R2, R11: 1M; R_Axial_DIN0207_L6.3mm_D2.5mm_P10.16mm_Horizontal
R3: 1K; R_Axial_DIN0207_L6.3mm_D2.5mm_P10.16mm_Horizontal
R4, R22, R29, R30, R31, R32: 1k; R_Axial_DIN0207_L6.3mm_D2.5mm_P10.16mm_Horizontal
R5, R7: 10K; R_Axial_DIN0207_L6.3mm_D2.5mm_P10.16mm_Horizontal
R6, R8, R9, R23, R24, R25: 2K; R_Axial_DIN0207_L6.3mm_D2.5mm_P10.16mm_Horizontal
R12: 47K; R_Axial_DIN0207_L6.3mm_D2.5mm_P10.16mm_Horizontal
R13, R14, R16, R17, R18, R19, R20, R21, R33: 330; R_Axial_DIN0207_L6.3mm_D2.5mm_P10.16mm_Horizontal
R26, R27, R28: 3k; R_Axial_DIN0207_L6.3mm_D2.5mm_P10.16mm_Horizontal
RV1: R_POT; Potentiometer_ACP_CA9-V10_Vertical
SW1: Reset; SW_TH_Tactile_Omron_B3F-10xx
U1, U9: 74LS32; DIP-14_W7.62mm_Socket
U2: Z80CPU; DIP-40_W15.24mm_Socket
U3: 28C256; DIP-28_W15.24mm_Socket_Large_Holes
U4: 74LS393; DIP-14_W7.62mm_Socket
U5: 74LS04; DIP-14_W7.62mm_Socket
U6: 74LS138; DIP-16_W7.62mm_Socket
U7, U13: 74LS573; DIP-20_W7.62mm_Socket
U8: 74HC245; DIP-20_W7.62mm_Socket
U10: 5161AS; 7SegmentLED_LTS6760_LTS6780
U11: HM62256; DIP-28_W15.24mm_Socket
U12: NE555P; DIP-8_W7.62mm
U14: YM2149; DIP-40_W15.24mm_Socket
U15: 74HCT138; DIP-16_W7.62mm_Socket
U16: 74HC00; DIP-14_W7.62mm_Socket
X1: CXO_DIP8; Oscillator_DIP-8
Y1: Crystal; Crystal_HC52-8mm_Vertical

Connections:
+5V: C3.1, C4.1, C5.1, C6.1, C11.1, C12.1, C15.1, C16.1, C17.1, D1.2 (A), IC1.9 (VCC), IC2.24 (VCC), J1_5VtoSerial1.1, J3.2, J3.15, J4.14, J5.18 (Vcc), J8.1, J9.18, J11.18, J12.1, R1.1, R5.1, R7.1, R10.2, R11.1, R12.1, R15.1, R34.2, RV1.3, U1.14 (VCC), U2.11 (VCC), U2.25 (~BUSRQ~), U3.27 (~WE), U3.28 (VCC), U4.14 (VCC), U5.14 (VCC), U6.16 (VCC), U7.20 (VCC), U8.20 (VCC), U9.14 (VCC), U11.28 (VCC), U12.4 (R), U12.8 (VCC), U13.20 (VCC), U14.25 (A8), U14.28 (BC2), U14.40 (VCC), U15.16 (VCC), U16.14 (VCC), X1.8 (Vcc)
/A0: IC1.34 (B/A), IC2.18 (CS0), J5.16 (A0), J9.16, U2.30 (A0), U3.10 (A0), U11.10 (A0), U13.2 (D0), U15.1 (A0)
/A1: IC1.33 (C/D), IC2.19 (CS1), J5.15 (A1), J9.15, U2.31 (A1), U3.9 (A1), U11.9 (A1), U13.3 (D1), U15.2 (A1)
/A2: J5.14 (A2), J9.14, U2.32 (A2), U3.8 (A2), U11.8 (A2), U13.4 (D2), U15.4 (E1)
/A3: J5.13 (A3), J9.13, U2.33 (A3), U3.7 (A3), U11.7 (A3), U13.5 (D3)
/A4: J5.12 (A4), J9.12, U2.34 (A4), U3.6 (A4), U6.4 (E1), U11.6 (A4), U13.6 (D4)
/A5: J5.11 (A5), J9.11, U2.35 (A5), U3.5 (A5), U6.1 (A0), U11.5 (A5), U13.7 (D5)
/A6: J5.10 (A6), J9.10, U2.36 (A6), U3.4 (A6), U6.2 (A1), U11.4 (A6), U13.8 (D6)
/A7: J5.9 (A7), J9.9, U2.37 (A7), U3.3 (A7), U6.3 (A2), U11.3 (A7), U13.9 (D7)
/A8: J5.8 (A8), J9.8, U2.38 (A8), U3.25 (A8), U11.25 (A8)
/A9: J5.7 (A9), J9.7, U2.39 (A9), U3.24 (A9), U11.24 (A9)
/A10: J5.6 (A10), J9.6, U2.40 (A10), U3.21 (A10), U11.21 (A10)
/A11: J5.5 (A11), J9.5, U2.1 (A11), U3.23 (A11), U11.23 (A11)
/A12: J5.4 (A12), J9.4, U2.2 (A12), U3.2 (A12), U11.2 (A12)
/A13: J5.3 (A13), J9.3, U2.3 (A13), U3.26 (A13), U11.26 (A13)
/A14: J5.2 (A14), J9.2, U2.4 (A14), U3.1 (A14), U11.1 (A14)
/A15: J5.1 (A15), J9.1, JP10.1 (A), U2.5 (A15), U5.5
/AO0: J3.4, J4.6, U13.19 (Q0)
/AO1: J3.5, J4.8, U13.18 (Q1)
/AO2: J3.6, J4.10, U13.17 (Q2)
/AO3: J4.12, U13.16 (Q3)
/BC1: U14.29 (BC1), U16.6
/BDIR: U14.27 (BDIR), U16.3
/CLK: IC1.20 (CLK), IC2.15 (CLK), J5.21 (~CLK~), J9.21, JP1.2 (B), JP2.2 (B), JP3.2 (B), JP4.2 (B), U2.6 (~CLK~)
/CLK_BASE: IC2.23 (TRG0), J8.2, JP1.1 (A), JP5.2 (B), JP6.2 (B), U4.1 (CP)
/D0: IC1.40 (D0), IC2.25 (D0), J5.27 (D0), J9.27, U2.14 (D0), U3.11 (D0), U7.2 (D0), U8.2 (A0), U11.11 (Q0), U14.37 (DA0)
/D1: IC1.1 (D1), IC2.26 (D1), J5.28 (D1), J9.28, U2.15 (D1), U3.12 (D1), U7.3 (D1), U8.3 (A1), U11.12 (Q1), U14.36 (DA1)
/D2: IC1.39 (D2), IC2.27 (D2), J5.29 (D2), J9.29, U2.12 (D2), U3.13 (D2), U7.4 (D2), U8.4 (A2), U11.13 (Q2), U14.35 (DA2)
/D3: IC1.2 (D3), IC2.28 (D3), J5.30 (D3), J9.30, U2.8 (D3), U3.15 (D3), U7.5 (D3), U8.5 (A3), U11.15 (Q3), U14.34 (DA3)
/D4: IC1.38 (D4), IC2.1 (D4), J5.31 (D4), J9.31, U2.7 (D4), U3.16 (D4), U7.6 (D4), U8.6 (A4), U11.16 (Q4), U14.33 (DA4)
/D5: IC1.3 (D5), IC2.2 (D5), J5.32 (D5), J9.32, U2.9 (D5), U3.17 (D5), U7.7 (D5), U8.7 (A5), U11.17 (Q5), U14.32 (DA5)
/D6: IC1.37 (D6), IC2.3 (D6), J5.33 (D6), J9.33, U2.10 (D6), U3.18 (D6), U7.8 (D6), U8.8 (A6), U11.18 (Q6), U14.31 (DA6)
/D7: IC1.4 (D7), IC2.4 (D7), J5.34 (D7), J9.34, U2.13 (D7), U3.19 (D7), U7.9 (D7), U8.9 (A7), U11.19 (Q7), U14.30 (DA7)
/DIO0: J3.7, J4.3, R13.2, U7.19 (Q0), U8.18 (B0)
/DIO1: J3.8, J4.5, R14.2, U7.18 (Q1), U8.17 (B1)
/DIO2: J3.9, J4.7, R16.2, U7.17 (Q2), U8.16 (B2)
/DIO3: J3.10, J4.9, R17.2, U7.16 (Q3), U8.15 (B3)
/DIO4: J3.11, J4.11, R18.2, U7.15 (Q4), U8.14 (B4)
/DIO5: J3.12, J4.13, R19.2, U7.14 (Q5), U8.13 (B5)
/DIO6: J3.13, J4.2, R20.2, U7.13 (Q6), U8.12 (B6)
/DIO7: J3.14, J4.4, R21.2, U7.12 (Q7), U8.11 (B7)
/DIV2: JP2.1 (A), U4.3 (Q0)
/DIV4: JP3.1 (A), U4.4 (Q1), U14.22 (CLOCK)
/DIV8: JP4.1 (A), U4.5 (Q2)
/IEI: IC2.13 (IEI), J5.22 (~INT~), J9.22, JP9.2 (B)
/IOA0: J11.3, U14.21 (IOA0)
/IOA1: J11.5, U14.20 (IOA1)
/IOA2: J11.7, U14.19 (IOA2)
/IOA3: J11.9, U14.18 (IOA3)
/IOA4: J11.11, U14.17 (IOA4)
/IOA5: J11.13, U14.16 (IOA5)
/IOA6: J11.15, U14.15 (IOA6)
/IOA7: J11.17, U14.14 (IOA7)
/IOB0: J11.2, U14.13 (IOB0)
/IOB1: J11.4, U14.12 (IOB1)
/IOB2: J11.6, U14.11 (IOB2)
/IOB3: J11.8, U14.10 (IOB3)
/IOB4: J11.10, U14.9 (IOB4)
/IOB5: J11.12, U14.8 (IOB5)
/IOB6: J11.14, U14.7 (IOB6)
/IOB7: J11.16, U14.6 (IOB7)
/RTS: IC1.17 (RTSA), R9.2
/RXA: IC1.12 (RXDA), J5.35, R6.2
/SIO_IEI: IC1.6 (IEI), IC2.11 (IEO)
/TXA: IC1.15 (TXDA), J5.36, R8.2
/UART_CLK: IC1.13 (RXCA), IC1.14 (TXCA), IC1.27 (RXTXCB), IC2.7 (TO0)
/V0: J3.3, RV1.2
/Y0_WR: U5.8, U7.11 (Load), U13.11 (Load)
/~INT~: IC1.5 (INT), R15.2, U2.16 (~INT~)
/~IORQ~: IC1.36 (IORQ), IC2.10 (IORQ), J5.26 (~IORQ~), J9.26, U2.20 (~IORQ~), U6.5 (E2)
/~M1~: IC1.8 (M1), IC2.14 (M1), J5.19 (~M1~), J9.19, U2.27 (~M1~), U6.6 (E3), U15.6 (E3)
/~MREQ~: J5.23 (~MREQ~), J9.23, U1.2, U1.4, U1.10, U2.19 (~MREQ~)
/~RD~: IC1.32 (RD), IC2.6 (RD), J5.25 (~RD~), J9.25, U1.1, U1.9, U2.21 (~RD~), U9.4
/~RESET~: IC1.21 (RESET), IC2.17 (RESET), J5.20 (~RESET~), J9.20, JP8.2 (B), R1.2, U2.26 (~RESET~), U14.23 (~RESET)
/~WR~: J5.24 (~WR~), J9.24, U1.5, U1.13, U2.22 (~WR~), U15.3 (A2)
/~Y0~: J7.1, U1.12, U6.15 (O0), U9.5
/~Y1~: J7.2, U6.14 (O1)
/~Y2~: IC1.35 (CE), J7.3, U6.13 (O2)
/~Y3~: IC2.16 (CE), J7.4, U6.12 (O3)
/~Y4~: J7.5, U6.11 (O4), U15.5 (E2)
/~Y5~: J5.37, J7.6, J9.37, U6.10 (O5)
/~Y6~: J5.38, J7.7, J9.38, U6.9 (O6)
/~Y7~: J5.39, J7.8, J9.39, U6.7 (O7)
GND: C1.2, C2.2, C3.2, C4.2, C5.2, C6.2, C8.2, C9.2, C10.1, C11.2, C12.2, C15.2, C16.2, C17.2, IC1.18 (CTSA), IC1.19 (DCDA), IC1.22 (DCDB), IC1.23 (CTSB), IC1.31 (GND), IC2.5 (GND), J1.1, J3.1, J3.16, J4.1, J5.17 (GND), J6.1, J8.3, J9.17, J10.1 (S), J11.1, J12.5, JP7.2 (B), R4.2, R22.2, R26.2, R27.2, R28.2, R33.2, RV1.1, SW1.1 (A), SW1.2 (A), U1.7 (GND), U2.29 (GND), U3.14 (GND), U4.2 (MR), U4.7 (GND), U5.7 (GND), U6.8 (GND), U7.10 (GND), U8.10 (GND), U9.7 (GND), U11.14 (GND), U12.1 (GND), U13.10 (GND), U14.1 (VSS), U14.24 (~A9), U15.8 (GND), U16.7 (GND), X1.4 (GND)
unnamed: C1.1, R2.2, U5.1, Y1.1
unnamed: C2.1, R3.2, Y1.2
unnamed: C8.1, R11.2, SW1.3 (B), SW1.4 (B), U12.2 (TR)
unnamed: C9.1, U12.5 (CV)
unnamed: C10.2, R12.2, U12.6 (THR), U12.7 (DIS)
unnamed: C13.1, J10.2 (R), J10.4
unnamed: C13.2, R29.1, R32.1
unnamed: C14.1, J10.3 (T), J10.5
unnamed: C14.2, R30.1, R31.1
unnamed: D1.1 (K), R33.1
unnamed: IC1.11 (SYNCA), R5.2
unnamed: IC1.24 (RTSB), R24.2
unnamed: IC1.26 (TXDB), R25.2
unnamed: IC1.28 (RXDB), R23.2
unnamed: IC1.29 (SYNCB), R7.2
unnamed: IC2.8 (TO1), J2.2
unnamed: IC2.9 (TO2), J2.4
unnamed: IC2.20 (TRG3), J2.5
unnamed: IC2.21 (TRG2), J2.3
unnamed: IC2.22 (TRG1), J2.1
unnamed: J1.2, R9.1
unnamed: J1.3, J1_5VtoSerial1.2, J6.3, J6.5, R25.1
unnamed: J1.4, R6.1
unnamed: J1.5, R8.1
unnamed: J6.2, R24.1
unnamed: J6.4, R23.1
unnamed: JP5.1 (A), X1.5 (OUT)
unnamed: JP6.1 (A), U5.4
unnamed: JP7.1 (A), U10.8 (CC)
unnamed: JP8.1 (A), U5.10
unnamed: JP9.1 (A), R10.1
unnamed: JP10.2 (B), JP11.2 (B), U3.20 (~CS)
unnamed: JP11.1 (A), R34.1
unnamed: R2.1, R3.1, U5.2, U5.3
unnamed: R4.1, U8.1 (A->B)
unnamed: R13.1, U10.7 (A)
unnamed: R14.1, U10.6 (B)
unnamed: R16.1, U10.4 (C)
unnamed: R17.1, U10.2 (D)
unnamed: R18.1, U10.1 (E)
unnamed: R19.1, U10.9 (F)
unnamed: R20.1, U10.10 (G)
unnamed: R21.1, U10.5 (DP)
unnamed: R22.1, U13.1 (OE)
unnamed: R26.1, R29.2, U14.3 (A)
unnamed: R27.1, R30.2, U14.4 (B)
unnamed: R28.1, R31.2, R32.2, U14.38 (C)
unnamed: U1.3, U11.22 (~OE)
unnamed: U1.6, U11.27 (~WE)
unnamed: U1.8, U3.22 (~OE)
unnamed: U1.11, U5.9
unnamed: U5.12, U7.1 (OE)
unnamed: U5.13, U8.19 (CE), U9.6
unnamed: U5.6, U11.20 (~CS)
unnamed: U5.11, U12.3 (Q)
unnamed: U15.9 (O6), U16.5
unnamed: U15.14 (O1), U16.2
unnamed: U15.15 (O0), U16.1, U16.4

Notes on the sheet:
Y0 = 7Seg, 8 Bit In/Out Y1 = Unused Y2 = Serial Y3 = CTC Y4 = Sound Base address
DTR
VCC
CTS
GND
for output too
IEI for graphics chip?
disable if u8 enabled?

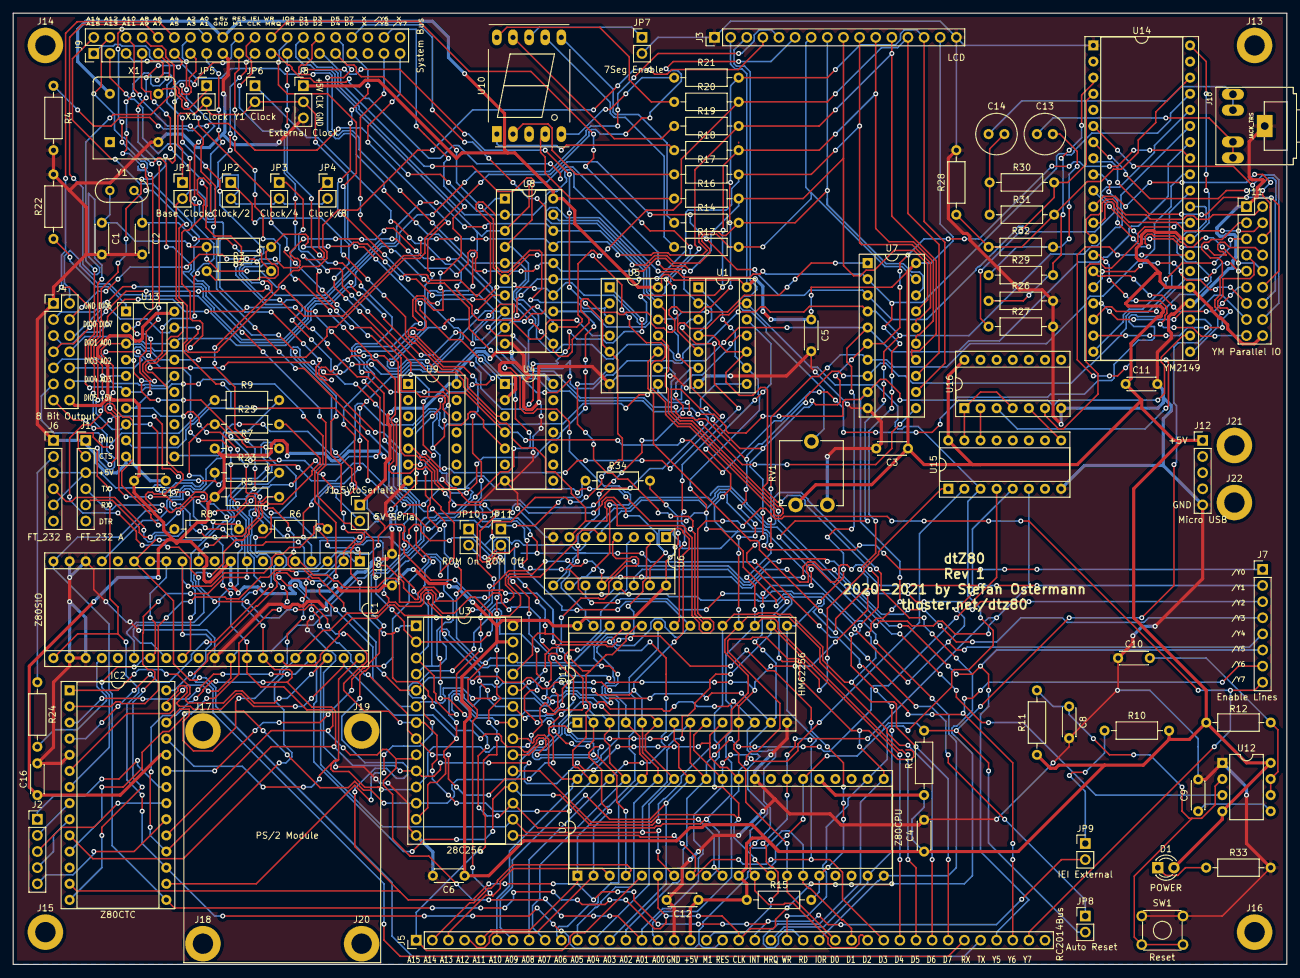
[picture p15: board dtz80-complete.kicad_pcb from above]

Board: 2 copper layers, 200.7 x 149.9 mm, 107 parts (0 on the bottom side), 142 nets.

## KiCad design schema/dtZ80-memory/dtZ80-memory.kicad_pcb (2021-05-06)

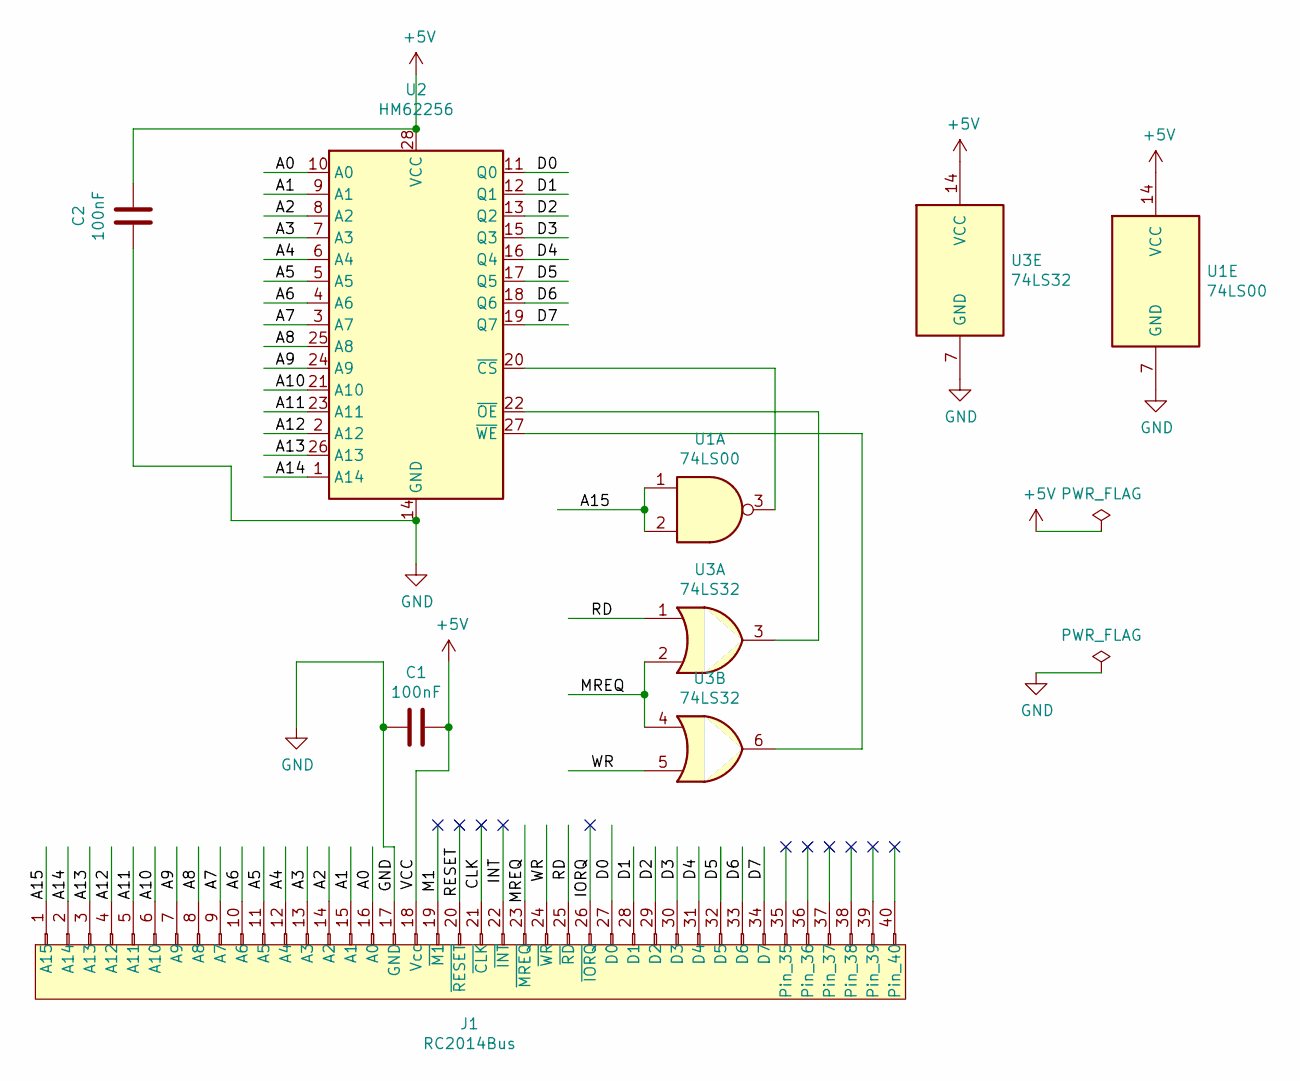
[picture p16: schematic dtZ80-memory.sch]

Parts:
C1, C2: 100nF; C_Disc_D3.0mm_W2.0mm_P2.50mm
J1: RC2014Bus
U1: 74LS00; DIP-14_W7.62mm_Socket
U2: HM62256; DIP-28_W15.24mm_Socket
U3: 74LS32; DIP-14_W7.62mm_Socket

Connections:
+5V: C1.1, C2.1, J1.18 (Vcc), U1.14 (VCC), U2.28 (VCC), U3.14 (VCC)
/A0: J1.16 (A0), U2.10 (A0)
/A1: J1.15 (A1), U2.9 (A1)
/A2: J1.14 (A2), U2.8 (A2)
/A3: J1.13 (A3), U2.7 (A3)
/A4: J1.12 (A4), U2.6 (A4)
/A5: J1.11 (A5), U2.5 (A5)
/A6: J1.10 (A6), U2.4 (A6)
/A7: J1.9 (A7), U2.3 (A7)
/A8: J1.8 (A8), U2.25 (A8)
/A9: J1.7 (A9), U2.24 (A9)
/A10: J1.6 (A10), U2.21 (A10)
/A11: J1.5 (A11), U2.23 (A11)
/A12: J1.4 (A12), U2.2 (A12)
/A13: J1.3 (A13), U2.26 (A13)
/A14: J1.2 (A14), U2.1 (A14)
/A15: J1.1 (A15), U1.1, U1.2
/CLK: J1.21 (~CLK~)
/D0: J1.27 (D0), U2.11 (Q0)
/D1: J1.28 (D1), U2.12 (Q1)
/D2: J1.29 (D2), U2.13 (Q2)
/D3: J1.30 (D3), U2.15 (Q3)
/D4: J1.31 (D4), U2.16 (Q4)
/D5: J1.32 (D5), U2.17 (Q5)
/D6: J1.33 (D6), U2.18 (Q6)
/D7: J1.34 (D7), U2.19 (Q7)
/INT: J1.22 (~INT~)
/IORQ: J1.26 (~IORQ~)
/M1: J1.19 (~M1~)
/MREQ: J1.23 (~MREQ~), U3.2, U3.4
/RD: J1.25 (~RD~), U3.1
/RESET: J1.20 (~RESET~)
/WR: J1.24 (~WR~), U3.5
GND: C1.2, C2.2, J1.17 (GND), U1.7 (GND), U2.14 (GND), U3.7 (GND)
unnamed: U1.3, U2.20 (~CS)
unnamed: U2.22 (~OE), U3.3
unnamed: U2.27 (~WE), U3.6

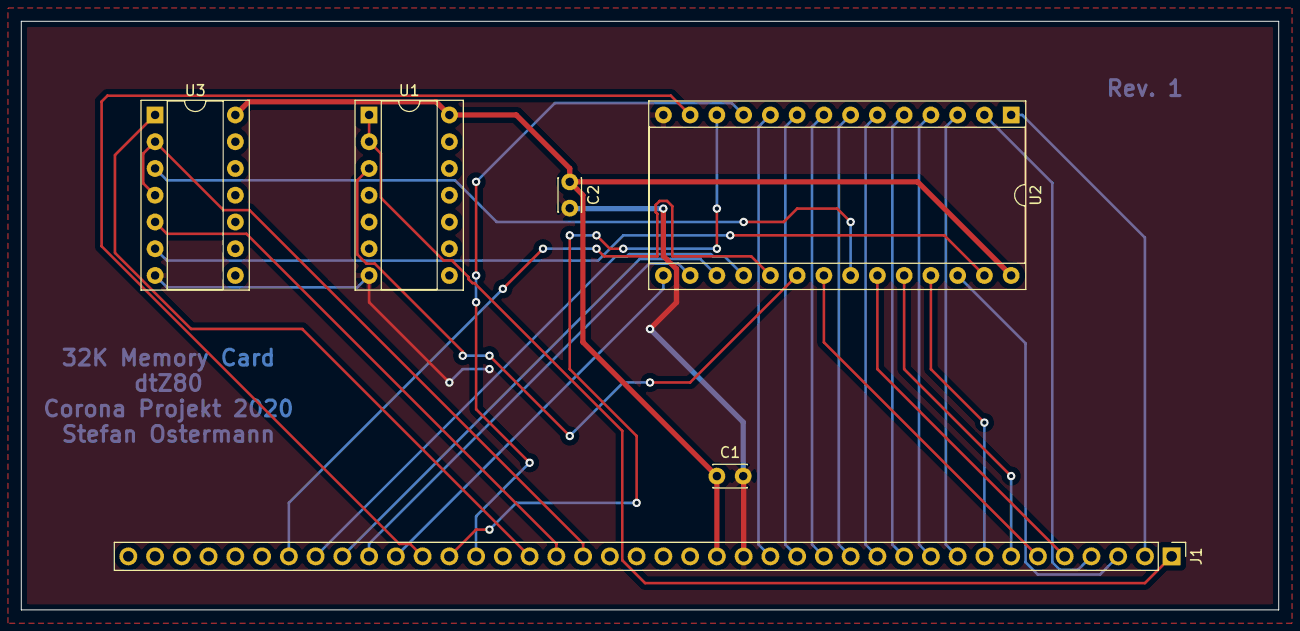
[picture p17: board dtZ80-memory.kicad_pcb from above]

Board: 2 copper layers, 119.4 x 55.9 mm, 6 parts (0 on the bottom side), 32 nets.

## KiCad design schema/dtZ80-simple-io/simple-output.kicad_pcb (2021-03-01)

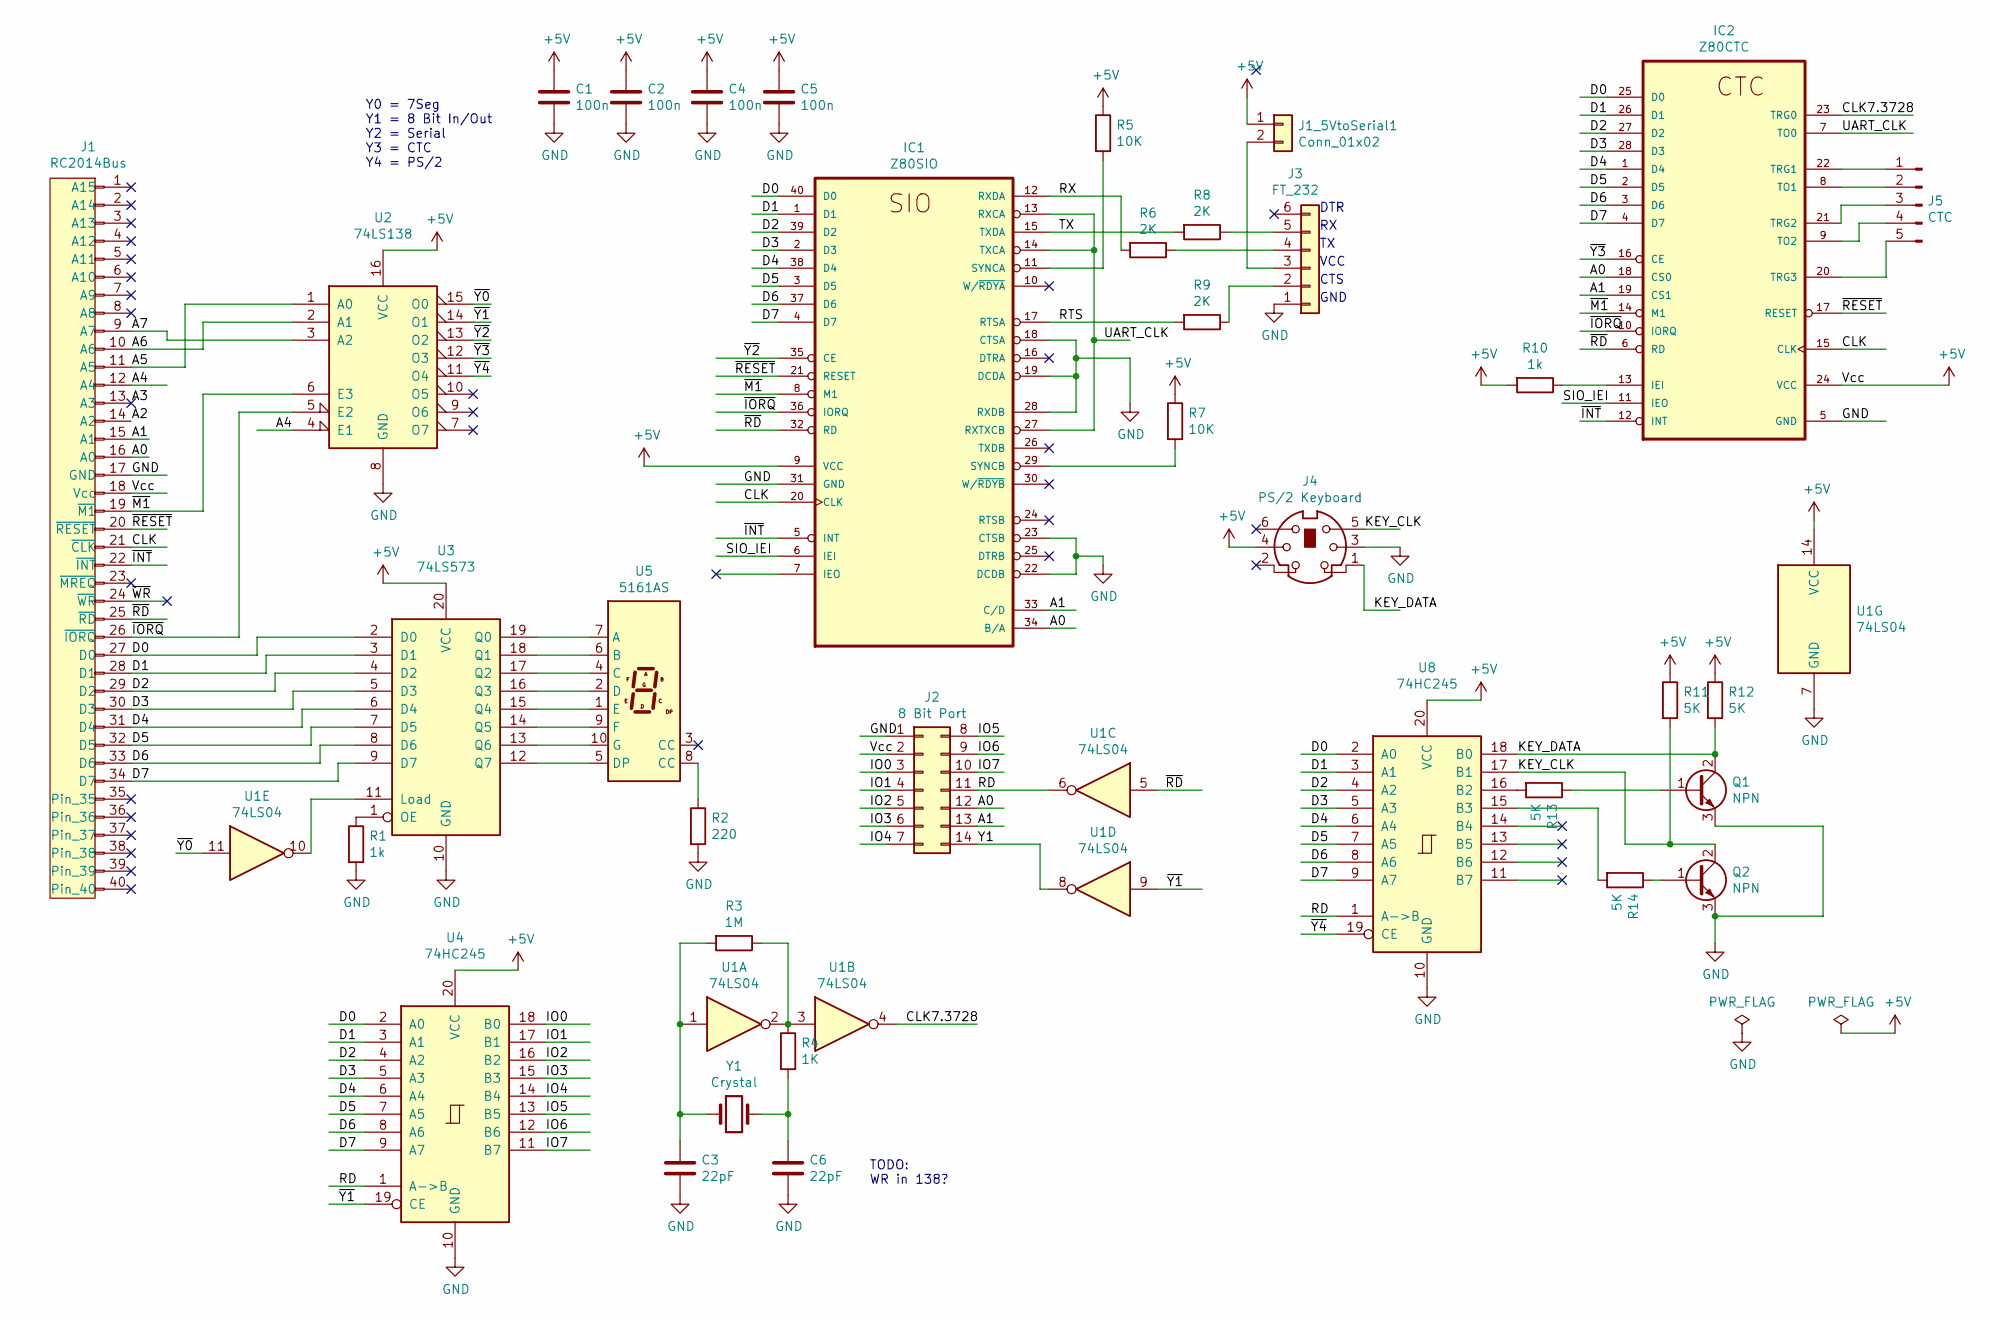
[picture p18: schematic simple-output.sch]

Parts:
C1, C2, C4, C5: 100n; C_Disc_D4.3mm_W1.9mm_P5.00mm
C3, C6: 22pF; C_Disc_D4.3mm_W1.9mm_P5.00mm
IC1: Z80SIO; DIP-40_W15.24mm_Socket
IC2: Z80CTC; DIP-28_W15.24mm_Socket
J1: RC2014Bus; PinHeader_1x40_P2.54mm_Vertical
J1_5VtoSerial1: Conn_01x02; PinHeader_1x02_P2.54mm_Vertical
J2: 8 Bit Port; PinHeader_2x07_P2.54mm_Vertical
J3: FT_232; PinHeader_1x06_P2.54mm_Vertical
J4: PS/2 Keyboard; Mini_DIN_6_TE_Connectivity
J5: CTC; PinHeader_1x05_P2.54mm_Vertical
Q1, Q2: NPN; TO-92_HandSolder
R1, R10: 1k; R_Axial_DIN0204_L3.6mm_D1.6mm_P5.08mm_Horizontal
R2: 220; R_Axial_DIN0204_L3.6mm_D1.6mm_P5.08mm_Horizontal
R3: 1M; R_Axial_DIN0204_L3.6mm_D1.6mm_P5.08mm_Horizontal
R4: 1K; R_Axial_DIN0204_L3.6mm_D1.6mm_P5.08mm_Horizontal
R5, R7: 10K; R_Axial_DIN0204_L3.6mm_D1.6mm_P5.08mm_Horizontal
R6, R8, R9: 2K; R_Axial_DIN0204_L3.6mm_D1.6mm_P5.08mm_Horizontal
R11, R12, R13, R14: 5K; R_Axial_DIN0204_L3.6mm_D1.6mm_P5.08mm_Horizontal
U1: 74LS04; DIP-14_W7.62mm_Socket
U2: 74LS138; DIP-16_W7.62mm_Socket
U3: 74LS573; DIP-20_W7.62mm_Socket
U4, U8: 74HC245; DIP-20_W7.62mm_Socket
U5: 5161AS; 7SegmentLED_LTS6760_LTS6780
Y1: Crystal; Crystal_HC49-U_Vertical

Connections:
+5V: C1.1, C2.1, C4.1, C5.1, IC1.9 (VCC), IC2.24 (VCC), J1.18 (Vcc), J1_5VtoSerial1.1, J2.2, J4.4, R5.1, R7.1, R10.2, R11.1, R12.1, U1.14 (VCC), U2.16 (VCC), U3.20 (VCC), U4.20 (VCC), U8.20 (VCC)
/A0: IC1.34 (B/A), IC2.18 (CS0), J1.16 (A0), J2.12
/A1: IC1.33 (C/D), IC2.19 (CS1), J1.15 (A1), J2.13
/A4: J1.12 (A4), U2.4 (E1)
/A5: J1.11 (A5), U2.1 (A0)
/A6: J1.10 (A6), U2.2 (A1)
/A7: J1.9 (A7), U2.3 (A2)
/CLK: IC1.20 (CLK), IC2.15 (CLK), J1.21 (~CLK~)
/CLK7.3728: IC2.23 (TRG0), U1.4
/D0: IC1.40 (D0), IC2.25 (D0), J1.27 (D0), U3.2 (D0), U4.2 (A0), U8.2 (A0)
/D1: IC1.1 (D1), IC2.26 (D1), J1.28 (D1), U3.3 (D1), U4.3 (A1), U8.3 (A1)
/D2: IC1.39 (D2), IC2.27 (D2), J1.29 (D2), U3.4 (D2), U4.4 (A2), U8.4 (A2)
/D3: IC1.2 (D3), IC2.28 (D3), J1.30 (D3), U3.5 (D3), U4.5 (A3), U8.5 (A3)
/D4: IC1.38 (D4), IC2.1 (D4), J1.31 (D4), U3.6 (D4), U4.6 (A4), U8.6 (A4)
/D5: IC1.3 (D5), IC2.2 (D5), J1.32 (D5), U3.7 (D5), U4.7 (A5), U8.7 (A5)
/D6: IC1.37 (D6), IC2.3 (D6), J1.33 (D6), U3.8 (D6), U4.8 (A6), U8.8 (A6)
/D7: IC1.4 (D7), IC2.4 (D7), J1.34 (D7), U3.9 (D7), U4.9 (A7), U8.9 (A7)
/IO0: J2.3, U4.18 (B0)
/IO1: J2.4, U4.17 (B1)
/IO2: J2.5, U4.16 (B2)
/IO3: J2.6, U4.15 (B3)
/IO4: J2.7, U4.14 (B4)
/IO5: J2.8, U4.13 (B5)
/IO6: J2.9, U4.12 (B6)
/IO7: J2.10, U4.11 (B7)
/KEY_CLK: J4.5, Q2.2 (C), R11.2, U8.17 (B1)
/KEY_DATA: J4.1, Q1.2 (C), R12.2, U8.18 (B0)
/RD: J2.11, U1.6, U4.1 (A->B), U8.1 (A->B)
/RTS: IC1.17 (RTSA), R9.2
/RX: IC1.12 (RXDA), R6.2
/SIO_IEI: IC1.6 (IEI), IC2.11 (IEO)
/TX: IC1.15 (TXDA), R8.2
/UART_CLK: IC1.13 (RXCA), IC1.14 (TXCA), IC1.27 (RXTXCB), IC2.7 (TO0)
/Y1: J2.14, U1.8
/~INT~: IC1.5 (INT), IC2.12 (INT), J1.22 (~INT~)
/~IORQ~: IC1.36 (IORQ), IC2.10 (IORQ), J1.26 (~IORQ~), U2.5 (E2)
/~M1~: IC1.8 (M1), IC2.14 (M1), J1.19 (~M1~), U2.6 (E3)
/~RD~: IC1.32 (RD), IC2.6 (RD), J1.25 (~RD~), U1.5
/~RESET~: IC1.21 (RESET), IC2.17 (RESET), J1.20 (~RESET~)
/~Y0~: U1.11, U2.15 (O0)
/~Y1~: U1.9, U2.14 (O1), U4.19 (CE)
/~Y2~: IC1.35 (CE), U2.13 (O2)
/~Y3~: IC2.16 (CE), U2.12 (O3)
/~Y4~: U2.11 (O4), U8.19 (CE)
GND: C1.2, C2.2, C3.2, C4.2, C5.2, C6.2, IC1.18 (CTSA), IC1.19 (DCDA), IC1.22 (DCDB), IC1.23 (CTSB), IC1.28 (RXDB), IC1.31 (GND), IC2.5 (GND), J1.17 (GND), J2.1, J3.1, J4.3, Q1.3 (E), Q2.3 (E), R1.2, R2.2, U1.7 (GND), U2.8 (GND), U3.10 (GND), U4.10 (GND), U8.10 (GND)
unnamed: C3.1, R3.2, U1.1, Y1.1
unnamed: C6.1, R4.2, Y1.2
unnamed: IC1.11 (SYNCA), R5.2
unnamed: IC1.29 (SYNCB), R7.2
unnamed: IC2.8 (TO1), J5.2
unnamed: IC2.9 (TO2), J5.4
unnamed: IC2.13 (IEI), R10.1
unnamed: IC2.20 (TRG3), J5.5
unnamed: IC2.21 (TRG2), J5.3
unnamed: IC2.22 (TRG1), J5.1
unnamed: J1_5VtoSerial1.2, J3.3
unnamed: J3.2, R9.1
unnamed: J3.4, R6.1
unnamed: J3.5, R8.1
unnamed: Q1.1 (B), R13.1
unnamed: Q2.1 (B), R14.1
unnamed: R1.1, U3.1 (OE)
unnamed: R2.1, U5.8 (CC)
unnamed: R3.1, R4.1, U1.2, U1.3
unnamed: R13.2, U8.16 (B2)
unnamed: R14.2, U8.15 (B3)
unnamed: U1.10, U3.11 (Load)
unnamed: U3.12 (Q7), U5.5 (DP)
unnamed: U3.13 (Q6), U5.10 (G)
unnamed: U3.14 (Q5), U5.9 (F)
unnamed: U3.15 (Q4), U5.1 (E)
unnamed: U3.16 (Q3), U5.2 (D)
unnamed: U3.17 (Q2), U5.4 (C)
unnamed: U3.18 (Q1), U5.6 (B)
unnamed: U3.19 (Q0), U5.7 (A)

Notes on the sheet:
TODO: WR in 138?
Y0 = 7Seg Y1 = 8 Bit In/Out Y2 = Serial Y3 = CTC Y4 = PS/2
DTR
VCC
CTS
GND

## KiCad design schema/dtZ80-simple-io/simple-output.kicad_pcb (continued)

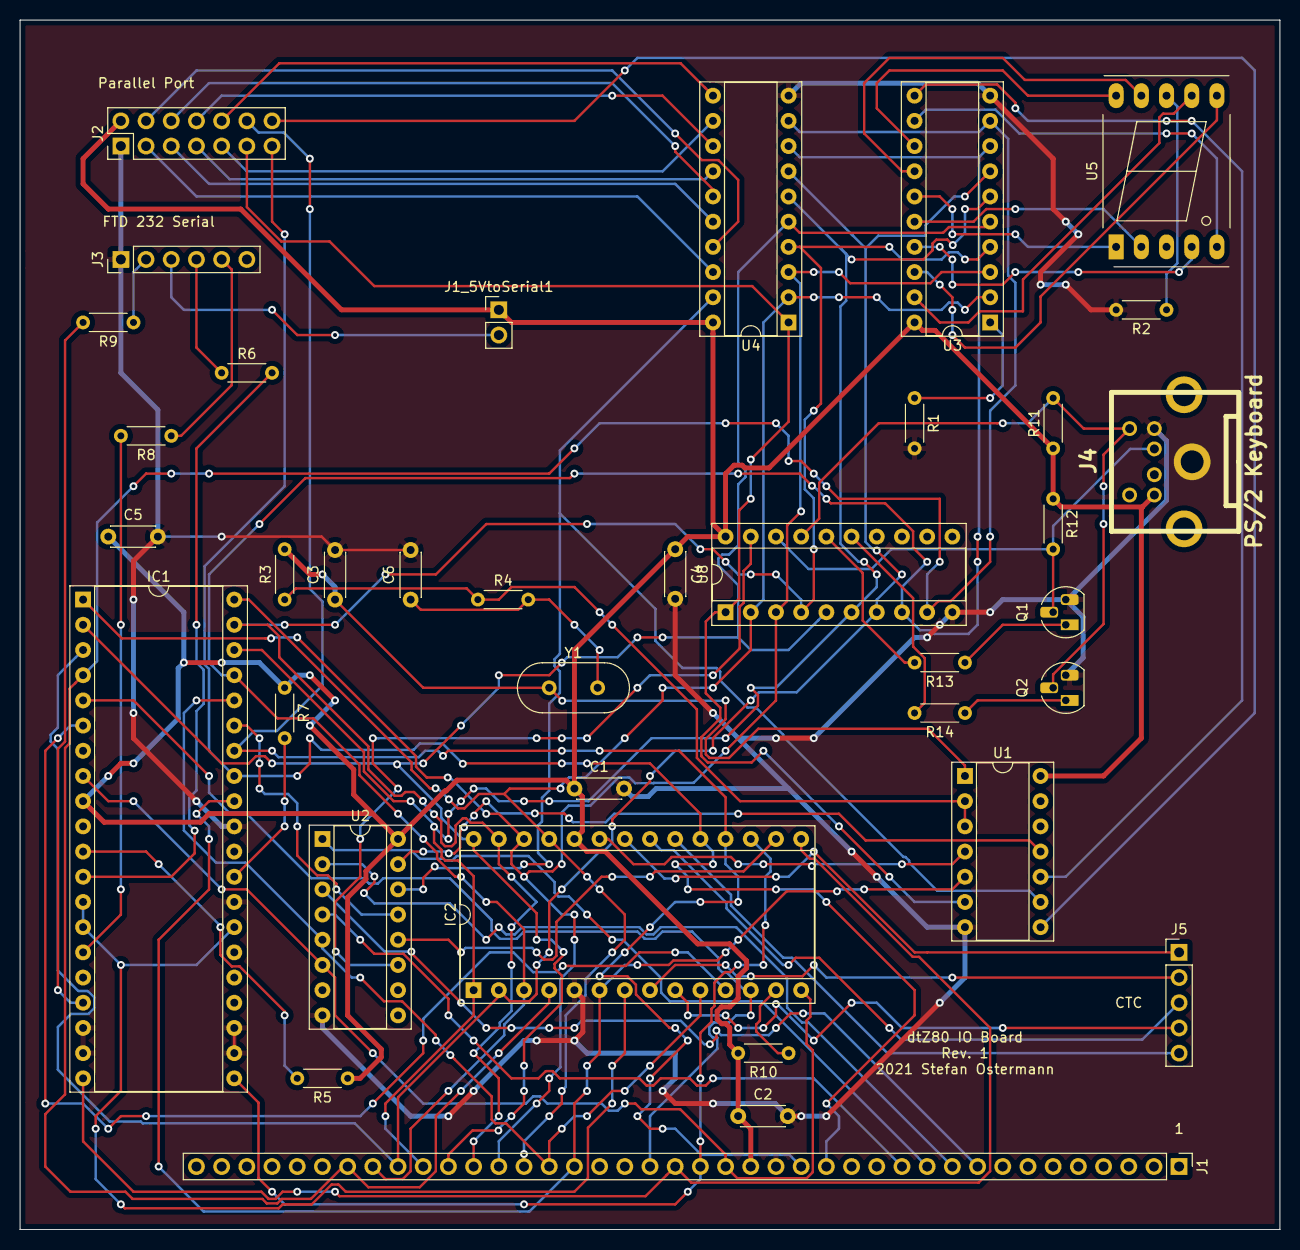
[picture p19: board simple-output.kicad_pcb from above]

Board: 2 copper layers, 127.0 x 121.9 mm, 37 parts (0 on the bottom side), 75 nets.

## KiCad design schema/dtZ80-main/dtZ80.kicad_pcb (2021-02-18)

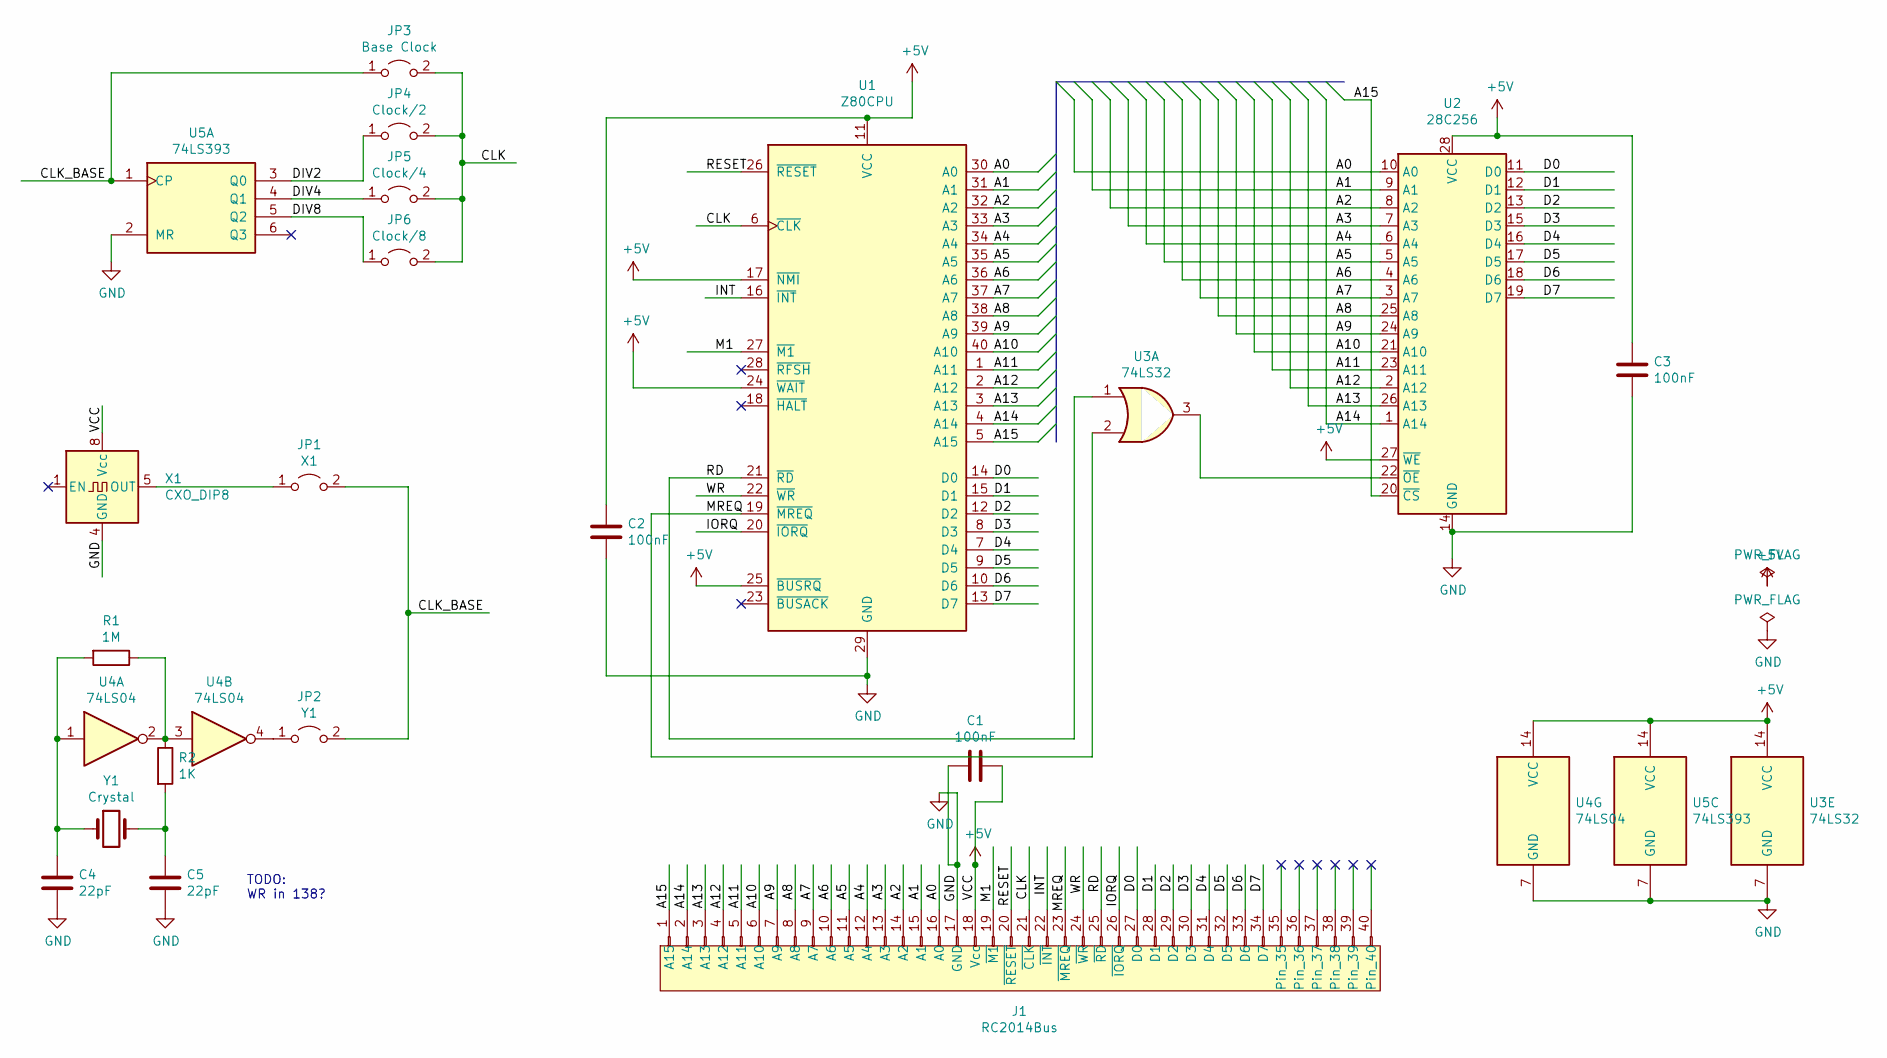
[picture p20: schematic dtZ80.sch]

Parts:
C1, C2, C3: 100nF; C_Disc_D3.0mm_W2.0mm_P2.50mm
C4, C5: 22pF; C_Disc_D4.3mm_W1.9mm_P5.00mm
J1: RC2014Bus; PinHeader_1x40_P2.54mm_Vertical
JP1: X1; PinHeader_1x02_P2.54mm_Vertical
JP2: Y1; PinHeader_1x02_P2.54mm_Vertical
JP3: Base Clock; PinHeader_1x02_P2.54mm_Vertical
JP4: Clock/2; PinHeader_1x02_P2.54mm_Vertical
JP5: Clock/4; PinHeader_1x02_P2.54mm_Vertical
JP6: Clock/8; PinHeader_1x02_P2.54mm_Vertical
R1: 1M; R_Axial_DIN0204_L3.6mm_D1.6mm_P5.08mm_Horizontal
R2: 1K; R_Axial_DIN0204_L3.6mm_D1.6mm_P5.08mm_Horizontal
U1: Z80CPU; DIP-40_W15.24mm
U2: 28C256; DIP-28_W15.24mm_Socket_Large_Holes
U3: 74LS32; DIP-14_W7.62mm
U4: 74LS04; DIP-14_W7.62mm_Socket
U5: 74LS393; DIP-14_W7.62mm_Socket
X1: CXO_DIP8; Oscillator_DIP-8
Y1: Crystal; Crystal_HC52-8mm_Vertical

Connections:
+5V: C1.1, C2.2, C3.2, J1.18 (Vcc), U1.11 (VCC), U1.17 (~NMI~), U1.24 (~WAIT~), U1.25 (~BUSRQ~), U2.27 (~WE), U2.28 (VCC), U3.14 (VCC), U4.14 (VCC), U5.14 (VCC), X1.8 (Vcc)
/A0: J1.16 (A0), U1.30 (A0), U2.10 (A0)
/A1: J1.15 (A1), U1.31 (A1), U2.9 (A1)
/A2: J1.14 (A2), U1.32 (A2), U2.8 (A2)
/A3: J1.13 (A3), U1.33 (A3), U2.7 (A3)
/A4: J1.12 (A4), U1.34 (A4), U2.6 (A4)
/A5: J1.11 (A5), U1.35 (A5), U2.5 (A5)
/A6: J1.10 (A6), U1.36 (A6), U2.4 (A6)
/A7: J1.9 (A7), U1.37 (A7), U2.3 (A7)
/A8: J1.8 (A8), U1.38 (A8), U2.25 (A8)
/A9: J1.7 (A9), U1.39 (A9), U2.24 (A9)
/A10: J1.6 (A10), U1.40 (A10), U2.21 (A10)
/A11: J1.5 (A11), U1.1 (A11), U2.23 (A11)
/A12: J1.4 (A12), U1.2 (A12), U2.2 (A12)
/A13: J1.3 (A13), U1.3 (A13), U2.26 (A13)
/A14: J1.2 (A14), U1.4 (A14), U2.1 (A14)
/A15: J1.1 (A15), U1.5 (A15), U2.20 (~CS)
/CLK: J1.21 (~CLK~), JP3.2 (B), JP4.2 (B), JP5.2 (B), JP6.2 (B), U1.6 (~CLK~)
/CLK_BASE: JP1.2 (B), JP2.2 (B), JP3.1 (A), U5.1 (CP)
/D0: J1.27 (D0), U1.14 (D0), U2.11 (D0)
/D1: J1.28 (D1), U1.15 (D1), U2.12 (D1)
/D2: J1.29 (D2), U1.12 (D2), U2.13 (D2)
/D3: J1.30 (D3), U1.8 (D3), U2.15 (D3)
/D4: J1.31 (D4), U1.7 (D4), U2.16 (D4)
/D5: J1.32 (D5), U1.9 (D5), U2.17 (D5)
/D6: J1.33 (D6), U1.10 (D6), U2.18 (D6)
/D7: J1.34 (D7), U1.13 (D7), U2.19 (D7)
/DIV2: JP4.1 (A), U5.3 (Q0)
/DIV4: JP5.1 (A), U5.4 (Q1)
/DIV8: JP6.1 (A), U5.5 (Q2)
/INT: J1.22 (~INT~), U1.16 (~INT~)
/IORQ: J1.26 (~IORQ~), U1.20 (~IORQ~)
/M1: J1.19 (~M1~), U1.27 (~M1~)
/MREQ: J1.23 (~MREQ~), U1.19 (~MREQ~), U3.2
/RD: J1.25 (~RD~), U1.21 (~RD~), U3.1
/RESET: J1.20 (~RESET~), U1.26 (~RESET~)
/WR: J1.24 (~WR~), U1.22 (~WR~)
GND: C1.2, C2.1, C3.1, C4.2, C5.2, J1.17 (GND), U1.29 (GND), U2.14 (GND), U3.7 (GND), U4.7 (GND), U5.2 (MR), U5.7 (GND), X1.4 (GND)
unnamed: C4.1, R1.2, U4.1, Y1.1
unnamed: C5.1, R2.2, Y1.2
unnamed: JP1.1 (A), X1.5 (OUT)
unnamed: JP2.1 (A), U4.4
unnamed: R1.1, R2.1, U4.2, U4.3
unnamed: U2.22 (~OE), U3.3

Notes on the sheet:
TODO: WR in 138?

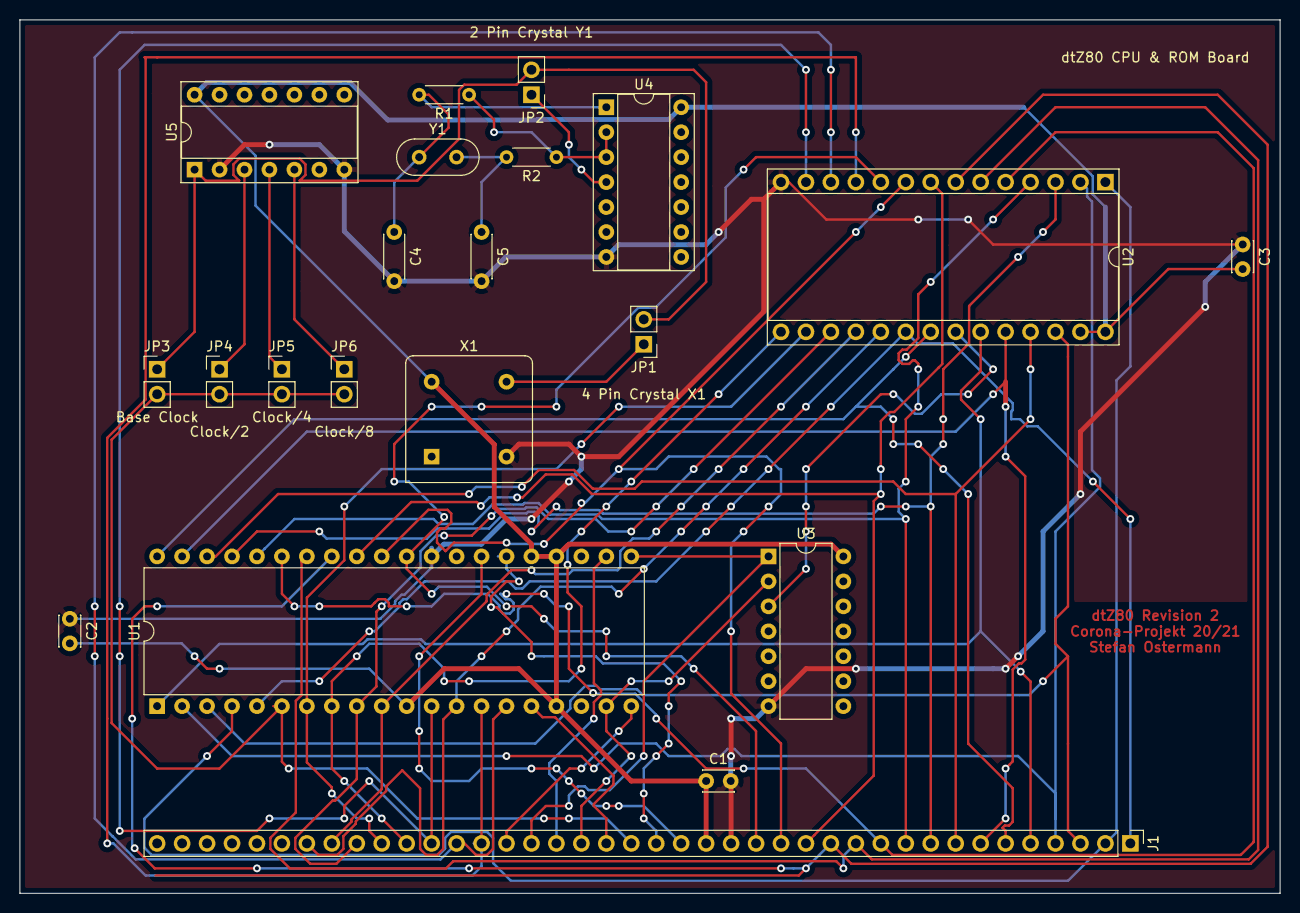
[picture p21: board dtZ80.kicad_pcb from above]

Board: 2 copper layers, 128.3 x 88.9 mm, 21 parts (0 on the bottom side), 44 nets.

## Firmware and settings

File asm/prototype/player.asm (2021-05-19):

;Universal PT2 and PT3 player for ZX Spectrum and MSX
;(c)2004-2007 S.V.Bulba <vorobey@mail.khstu.ru>
;http://bulba.untergrund.net (http://bulba.at.kz)
;adopted by Stefan Ostermann for the dtZ80 and rasm

;Only works if copied into RAM:
RAM_DEST
	EQU	$8000

stackpointer2
	EQU	$cfff  ;Address for the dtZ80 stack pointer



;Conditional assembly

;2) Current position counter at (START+11)
CurPosCounter = 0
;4) Allow loop checking and disabling
LoopChecker = 0

;Features
;--------
;-Can be compiled at any address (i.e. no need rounding ORG
; address).
;-Variables (VARS) can be located at any address (not only after
;code block).
;-INIT subprogram checks PT3-module version and rightly
; generates both note and volume tables outside of code block
; (in VARS).
;-Two portamento (spc. command 3xxx) algorithms (depending of
; PT3 module version).
;-New 1.XX and 2.XX special command behaviour (only for PT v3.7
; and higher).
;-Any Tempo value are accepted (including Tempo=1 and Tempo=2).
;-Fully compatible with Ay_Emul PT3 and PT2 players codes.
;-See also notes at the end of this source code.

;Limitations
;-----------
;-Can run in RAM only (self-modified code is used).
;-PT2 position list must be end by #FF marker only.

;Warning!!! PLAY subprogram can crash if no module are loaded
;into RAM or INIT subprogram was not called before.

;Call MUTE or INIT one more time to mute sound after stopping
;playing

	ORG	#0000
  ;copy into RAM:
	LD	SP,stackpointer2
	LD	HL,BOOTSTRAP_END ;Code to be moved
	LD	DE,RAM_DEST ;Destination address
	LD	BC,20000;guess how much bytes to copy
	LDIR                ;Copy
	JP	#8000
BOOTSTRAP_END:
ORG
	#8000,BOOTSTRAP_END
START_RAM:
  ;Show some numbers:
	LD	A,0
	LD	(ram_counter),A
	LD	A,1              ;Offset for the number to display
	CALL	segprint_num   ;Display number stored in a
	CALL	delay2
	LD	A,2
	CALL	segprint_num
	CALL	delay2
	CALL	inc_ram_counter
	CALL	ram_counter_segprint
	CALL	delay2
	CALL	inc_ram_counter
	CALL	ram_counter_segprint
	CALL	delay2
	CALL	start

	;ORG #100
	; ld hl, startupstr
  ; call print
;Test codes (commented)
	;LD A,2 ;PT2,ABC,Looped
	LD	A,0
	LD	(START+10),A
	CALL	START
	; ld hl, startupstr
	; call print
;	EI
;_LP	HALT
_LP
	CALL	START+5
	CALL	pause

	; XOR A
	; IN A,(#FE)
	; CPL
	; AND 15
	JR	_LP
	LD	HL,endstr
	;call print
	JR	START+8

TonA
	EQU	0
TonB
	EQU	2
TonC
	EQU	4
Noise
	EQU	6
Mixer
	EQU	7
AmplA
	EQU	8
AmplB
	EQU	9
AmplC
	EQU	10
Env
	EQU	11
EnvTp
	EQU	13

;Entry and other points
;START initialize playing of module at MDLADDR
;START+3 initialization with module address in HL
;START+5 play one quark
;START+8 mute
;START+10 setup and status flags
;START+11 current position value (byte) (optional)

START
	LD	HL,MDLADDR
	JR	INIT
	JP	PLAY
	JR	MUTE
SETUP
	DB	0 ;set bit0, if you want to play without looping
	     ;(optional);
	     ;set bit1 for PT2 and reset for PT3 before
	     ;calling INIT;
	     ;bits2-3: %00-ABC, %01 ACB, %10 BAC (optional);
	     ;bits4-6 are not used
	     ;bit7 is set each time, when loop point is passed
	     ;(optional)
	IF	CurPosCounter
CurPos
	DB	0 ;for visualization only (i.e. no need for playing)
	ENDIF


	IF	LoopChecker
CHECKLP
	LD	HL,SETUP
	SET	7,(HL)
	BIT	0,(HL)
	RET	Z
	POP	HL
	LD	HL,DelyCnt
	INC	(HL)
	LD	HL,ChanA+CHP.NtSkCn
	INC	(HL)
	ENDIF

MUTE
	XOR	A
	LD	H,A
	LD	L,A
	LD	(AYREGS+AmplA),A
	LD	(AYREGS+AmplB),HL
	JP	ROUT

INIT
;HL - AddressOfModule
	CALL	inc_ram_counter
	CALL	ram_counter_segprint
	CALL	delay2
	LD	A,(START+10)
	AND	2
	JR	NZ,INITPT2

	CALL	SETMDAD
	PUSH	HL
	LD	DE,100
	ADD	HL,DE
	LD	A,(HL)
	LD	(Delay),A
	PUSH	HL
	POP	IX
	ADD	HL,DE
	LD	(CrPsPtr),HL
	LD	E,(IX+102-100)
	INC	HL

	IF	CurPosCounter
	LD	A,L
	LD	(PosSub+1),A
	ENDIF

	ADD	HL,DE
	LD	(LPosPtr),HL
	POP	DE
	LD	L,(IX+103-100)
	LD	H,(IX+104-100)
	ADD	HL,DE
	LD	(PatsPtr),HL
	LD	HL,169
	ADD	HL,DE
	LD	(OrnPtrs),HL
	LD	HL,105
	ADD	HL,DE
	LD	(SamPtrs),HL
	LD	A,(IX+13-100) ;EXTRACT VERSION NUMBER
	SUB	#30
	JR	C,L20
	CP	10
	JR	C,L21
L20
	LD	A,6
L21
	LD	(Version),A
	PUSH	AF ;VolTable version
	CP	4
	LD	A,(IX+99-100) ;TONE TABLE NUMBER
	RLA
	AND	7
	PUSH	AF ;NoteTable number
	LD	HL,(e_-SamCnv-2)*256+#18
	LD	(SamCnv),HL
	LD	A,#BA
	LD	(OrnCP),A
	LD	(SamCP),A
	LD	A,#7B
	LD	(OrnLD),A
	LD	(SamLD),A
	LD	A,#87
	LD	(SamClc2),A
	LD	BC,PT3PD
	LD	HL,0
	LD	DE,PT3EMPTYORN
	JR	INITCOMMON

INITPT2
	LD	A,(HL)
	LD	(Delay),A
	PUSH	HL
	PUSH	HL
	PUSH	HL
	INC	HL
	INC	HL
	LD	A,(HL)
	INC	HL
	LD	(SamPtrs),HL
	LD	E,(HL)
	INC	HL
	LD	D,(HL)
	POP	HL
	AND	A
	SBC	HL,DE
	CALL	SETMDAD
	POP	HL
	LD	DE,67
	ADD	HL,DE
	LD	(OrnPtrs),HL
	LD	E,32
	ADD	HL,DE
	LD	C,(HL)
	INC	HL
	LD	B,(HL)
	LD	E,30
	ADD	HL,DE
	LD	(CrPsPtr),HL
	LD	E,A
	INC	HL

	IF	CurPosCounter
	LD	A,L
	LD	(PosSub+1),A
	ENDIF

	ADD	HL,DE
	LD	(LPosPtr),HL
	POP	HL
	ADD	HL,BC
	LD	(PatsPtr),HL
	LD	A,5
	LD	(Version),A
	PUSH	AF
	LD	A,2
	PUSH	AF
	LD	HL,#51CB
	LD	(SamCnv),HL
	LD	A,#BB
	LD	(OrnCP),A
	LD	(SamCP),A
	LD	A,#7A
	LD	(OrnLD),A
	LD	(SamLD),A
	LD	A,#80
	LD	(SamClc2),A
	LD	BC,PT2PD
	LD	HL,#8687
	LD	DE,PT2EMPTYORN

INITCOMMON

	LD	(PTDECOD+1),BC
	LD	(PsCalc),HL
	PUSH	DE

;note table data depacker
;(c) Ivan Roshin
	LD	DE,T_PACK
	LD	BC,T1_+(2*49)-1
TP_0
	LD	A,(DE)
	INC	DE
	CP	15*2
	JR	NC,TP_1
	LD	H,A
	LD	A,(DE)
	LD	L,A
	INC	DE
	JR	TP_2
TP_1
	PUSH	DE
	LD	D,0
	LD	E,A
	ADD	HL,DE
	ADD	HL,DE
	POP	DE
TP_2
	LD	A,H
	LD	(BC),A
	DEC	BC
	LD	A,L
	LD	(BC),A
	DEC	BC
	SUB	#F8*2
	JR	NZ,TP_0

	IF	LoopChecker
	LD	HL,SETUP
	RES	7,(HL)

	IF	CurPosCounter
	INC	HL
	LD	(HL),A
	ENDIF

	ELSE

	IF	CurPosCounter
	LD	(CurPos),A
	ENDIF

	ENDIF

	LD	HL,VARS
	LD	(HL),A
	LD	DE,VARS+1
	LD	BC,VAR0END-VARS-1
	LDIR
	LD	(AdInPtA),HL ;ptr to zero
	INC	A
	LD	(DelyCnt),A
	LD	HL,#F001 ;H - CHP.Volume, L - CHP.NtSkCn
	LD	(ChanA+CHP.NtSkCn),HL
	LD	(ChanB+CHP.NtSkCn),HL
	LD	(ChanC+CHP.NtSkCn),HL
	POP	HL
	LD	(ChanA+CHP.OrnPtr),HL
	LD	(ChanB+CHP.OrnPtr),HL
	LD	(ChanC+CHP.OrnPtr),HL

	POP	AF

;NoteTableCreator (c) Ivan Roshin
;A - NoteTableNumber*2+VersionForNoteTable
;(xx1b - 3.xx..3.4r, xx0b - 3.4x..3.6x..VTII1.0)

	LD	HL,NT_DATA
	PUSH	DE
	LD	D,B
	ADD	A,A
	LD	E,A
	ADD	HL,DE
	LD	E,(HL)
	INC	HL
	SRL	E
	SBC	A,A
	AND	#A7 ;#00 (NOP) or #A7 (AND A)
	LD	(L3),A
	EX	DE,HL
	POP	BC ;BC=T1_
	ADD	HL,BC

	LD	A,(DE)
	ADD	A,T_
	LD	C,A
	ADC	A,T_/256
	SUB	C
	LD	B,A
	PUSH	BC
	LD	DE,NT_
	PUSH	DE

	LD	B,12
L1
	PUSH	BC
	LD	C,(HL)
	INC	HL
	PUSH	HL
	LD	B,(HL)

	PUSH	DE
	EX	DE,HL
	LD	DE,23
	LD	IXH,8

L2
	SRL	B
	RR	C
L3
	DB	#19	;AND A or NOP
	LD	A,C
	ADC	A,D	;=ADC 0
	LD	(HL),A
	INC	HL
	LD	A,B
	ADC	A,D
	LD	(HL),A
	ADD	HL,DE
	DEC	IXH
	JR	NZ,L2

	POP	DE
	INC	DE
	INC	DE
	POP	HL
	INC	HL
	POP	BC
	DJNZ	L1

	POP	HL
	POP	DE

	LD	A,E
	CP	TCOLD_1
	JR	NZ,CORR_1
	LD	A,#FD
	LD	(NT_+#2E),A

CORR_1
	LD	A,(DE)
	AND	A
	JR	Z,TC_EXIT
	RRA
	PUSH	AF
	ADD	A,A
	LD	C,A
	ADD	HL,BC
	POP	AF
	JR	NC,CORR_2
	DEC	(HL)
	DEC	(HL)
CORR_2
	INC	(HL)
	AND	A
	SBC	HL,BC
	INC	DE
	JR	CORR_1

TC_EXIT

	POP	AF
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

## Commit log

2021-01-10 more assembler
2021-02-06 Reworked Boards
    [dtZ80-memory.sch, dtZ80.kicad_pcb, dtZ80.sch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]
2021-02-28 IO Board Rev 1
    [connections.sch, dtz80-complete.kicad_pcb, dtz80-complete.sch]
2021-03-01 CTC & Fixes on IO Board
    [simple-output.kicad_pcb, simple-output.sch]
2021-04-11 reset circuit
    [dtz80-complete.sch]
2021-04-25 schema, datasheets etc
    [dtz80-complete.sch]
2021-05-04 full schema
    [dtz80-complete.kicad_pcb]
2021-05-06 Schema completet
    [dtz80-complete.kicad_pcb, dtz80-complete.sch]
2021-05-06 gerber files
    [dtZ80-B_Cu.gbr, dtZ80-B_Mask.gbr, dtZ80-B_SilkS.gbr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]
2021-05-06 Cleanups, PDF-Exports
    [dtZ80-memory.kicad_pcb, dtZ80-memory.sch, dtz80-complete.kicad_pcb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]
2021-05-19 complete schema, first assembler tests
    [dtz80-complete-B_Cu.gbl, dtz80-complete-B_Mask.gbs, dtz80-complete-B_Paste.gbp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]
2021-05-24 Black dtZ80 complete board and ASM code
    [dtz80-complete.kicad_pcb]
2022-08-27 Formatting, Cleanups, Fixing asm errors
    [player.asm]
2025-08-04 ai improvements, case
    [dtz80-case.step]
